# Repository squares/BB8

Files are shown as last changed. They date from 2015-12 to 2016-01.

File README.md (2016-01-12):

// ROAD MAP //

Version 1.0 - Complete

-->  CURRENT 1.5  - I have sound sort of working.  I'm trying to get this working in the least intrusive way possible. Ideally, you'll be able to just buy a wave shield from adafruit and slam it into the top of the arduino and be done with it. That's the hope anyway.

Version 2.0 - Sound Module - Will include randomized sounds that play at randomized intervals.  Perhaps integrate an external power switch.

Version 3.0 - External stimulus for sound module - Considering IR, zigbee, wifi, raspberry pi interface, others.

Version 4.0 - Likely final - Will provide open ends for communication with external components (body, other network devices)... Perhaps moving the audio out of the dome into the body.

//
UPDATE 2016-01-12

Patrick Stefanski was awesome enough to design a modified dome plate and a holder.  This allows you to secure the USB power brick vertically inside of the dome and provides access to the charging port (and slightly useful power-test button) on the bottom of the USB charger.

Once I find time, I'm going to attempt to hack together a power switch onto a USB cable and drop another hole next to this so you can turn the lights on and off without ever having to open up the dome.

UPDATE 2015-12-27

For whatever reason, git desktop decided not to push up the stl's and the png that contains the breadboard layout version of the schematic.  I corrected that and those files are now available.  A couple of things about the breadboard layout:

* - Don't use 220ohm resistors on the entire RGB LED.  Every RGB LED I've seen uses something different.  Mine took 100ohm resistors on the green and blue pins.  Just check the data sheet for whatever you buy.
* - The diagram also doesn't show the power indicator LED.  This is totally optional, but I like being able to verify that the board is getting power.
* - This can be compressed significantly, using the board I show in the parts list. Look at either of the Board images in the images folder for an example.  Board2 is the latest approach, and allows you to create a wiring harness with the common cathode pin glued to the anodes.  This way, you can just plug in the entire block and not have to fiddle with it.  This version also requires less soldering.  I'll put up a picture of the solder points shortly.
* - Last but not least... just wanted to add a quick note that you probably shouldn't run this off the 5v pin. I do.. and my LEDs are BRIGHT.  But I have no idea what that's going to do to the life of my LEDs.  I imagine they will burn out quicker, but I run my board infrequently enough that I won't mind printing and replacing the LED harnesses eventually. Anyway, just wanted to drop a note about that consideration.

//

If you've found this repo, you're interested in adding internal electronics to your BB8 Dome.


All of the options I'd seen involved using every single pin of an arduino to light the logic panels on the dome.  Unfortunately, that removed the ability to do anything more interesting with the lighting, because you'd very quickly run out of PWM capable pins. So, I decided to create a version that utilizes shift registers to extend the capabilities a bit.



I’ve finally finished version 1.0 of my standalone lighting for the dome. I’ve had a lot of people ask me to post schematics, code, and parts lists… and I finally feel like it’s at a good point to do so. 

Regarding the schematic - The schematic shows 220ohm resistors for ALL of the LEDs. This is incorrect. The green and blue legs for the RGB LEDs generally use a lower value resistor. In my case, they’re using 100ohm resistors. Please check your spec sheets for whatever RGB LEDs you get.

Regarding the program - The program requires three libraries (included in the archive). ShiftPWM, which allows you to extend the number of addressable LEDs using shift registers. Arduino Thread, which facilitates (or simulates anyway) multi-threaded operation, and LogicBlock, which is custom code that I’m writing. The sketch itself, along with the LogicBlock library, are the two components of this that I’ve written from the ground up, and will be modifying over time. In future releases, I’ll only be including those two components.

Regarding the parts list (<a href="https://docs.google.com/spreadsheets/d/1KzJZGZxBMD4uZg5txSiHm7NLZ_BNpFicUeiCb588h9Q/edit#gid=0">Google Sheets Parts List for BB8 Internals</a>)- So, full disclosure: I’m VERY impatient. I buy everything on Amazon Prime, because I’m going to get whatever it is in two days, in most cases. So the links I’ve included in the parts sheet are all to amazon prime pages. You CAN find these parts cheaper elsewhere.. you can also likely find them in smaller quantities… for what it’s worth, I found that you’re really only saving a couple bucks elsewhere… but you might have better sources than me. I’ve been really happy with the quality of the parts I’ve ordered.

As a result of my Amazon purchase history, I have a surplus of parts… and as such, I’m willing to put together parts kits for those of you that are willing/able to solder your own setup. I’ve broken down the cost per part for everything I used in my build, and listed that out in the parts sheet. Just to be totally clear, I’m not marking up the price of each part, but I am charging a couple of bucks “handling” for getting everything bagged in anti-static container and organized into envelopes/packages.

I’ve also designed an enclosure to house all of this and keep it looking nice inside my dome. I’ll be happy to share the STLs for that if anyone is interested… but it’s pretty purpose specific to the board I’ve designed.

All of that said, there have been several people that have asked me if I would build this for them, and I’m willing to do that. I’ve included a few options for how that can happen (purchasing arduinos, optional parts, etc) in the parts list spreadsheet. If you think that’s something you might be interested in, feel free to reach out and we can discuss what you might need.

TO DO
-----
* Write up assembly instructions
* Update schematic to reflect 100 ohm resistors, and include power indicator led
* Continue working on v2 (sound add-on)

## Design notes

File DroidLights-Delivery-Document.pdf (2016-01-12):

Thank

you

for

buying

a

set

of

DroidLights.
Before

you

do

ANYTHING…
Please

take

a

moment

to

read

the

guidelines

and

disclaimers

at

the

end

of

this
document!

Now

that

all

of

that

is

out

of

the

way… let’s

get

started!

Upon

opening

the

package,

you

you

find

that

I

have

assembled

the

DroidLight

kits

completely.

If

you

want

to

jump

ahead

and

start

your

lights

up,

skip

ahead

to

the

“CONNECTING

TO

THE
ARDUINO” section.

You

should

be

able

to

immediately

plug

in

the

power

adaptor,

and

have
lights

flickering

away.

The

lights

will all

pulse

for

around

5

seconds

(or

approx.. 3

pulses),

and
then

start

cycling

through

random

behaviors.

In

the

very

unlikely

event

that

any

of

the

lights

come

unplugged

from

the

board during
shipping,

or,

if

in

the

future,

you

wish

to

swap

out

the

LEDs

for

some

reason,

please

skip

below
to

the

section

labeled

“WIRING

HARNESS

INSTALLATION”.

I’m

making

every

effort

to

ensure
that

the

lighting

system

arrives

completely

in

tact,

but

things

can

shift

in

transit.

All

I

can
guarantee

is

that

the

lighting

system

was

100%

functional

per

my

specs

when

I

closed

up

the
package.

INSTALLING

YOUR

DROIDLIGHTS

I’ve

printed

the LED

housings

per

the

specs

outlined

in

the

group’s

documentation… however,
it’s

entirely

possible

that

the

printer used

for

your

dome

parts

is

calibrated

slightly

differently,
and

the

lenses

are

likely

not

to fit

right

out

of

the

box.

There

are

several

approaches

to

making
a

nice

fit,

but

the

one

I’ve

found

works

best

is

as

follows:

1. First,

ensure

that

the

dome

openings

are

smooth

and

free

of

excess

paint/filler/support
materials.

We’re

looking

for

as

smooth

and

square

as

possible

finish

inside

there.

Test
the part

to

see

if

it

fits

into

the

opening

(first

time

through,

it

likely

won’t)
2. Lightly

sand all

four

outside

edges

of

the logic

housing.

I

printed

these

with

several
shells,

so

you

should

be

able

to

sand

quite

a

bit

without

causing

any

major

issues,

but
just

start

with

a

light

sand

on

each

edge.
3. Repeat

step

1.

That’s

it

really… just

slowly

wear

away

the

logic

housing

until

the

light
fits

into

the

opening. You’re

going

for

a snug

fit.

It

shouldn’t

require

a

great

deal

of
force

to

push

in,

but

likewise,

shouldn’t

just

pop

out.

You

can

also

carefully

round

the
front

face

to

make

the

initial

insertion

easier.

But

keep

in

mind,

that

the

lower

logic
housings

are

very

close

to

a

seam,

and

there’s

not

a

lot

of

material

printed

around
there… if

you

force

them

in,

you

run

the

risk

of

cracking

your

dome.

So

shape

them
appropriately.

4. If you

do

over-‐sand,

and

the

lenses

no

longer

stay

in,

a

drop

of

hot

glue should

be
sufficient

to

hold

it

in place.

The single

red

radar

LED is

only

slightly

more

complicated

to

install.

For

my

dome,

I

hot

glued
the

LED

into

the

back

of

the

radar

eye

internals,

and

then

fed

the

wires

into

the

dome

through
the

surround.

If

you’ve

glued

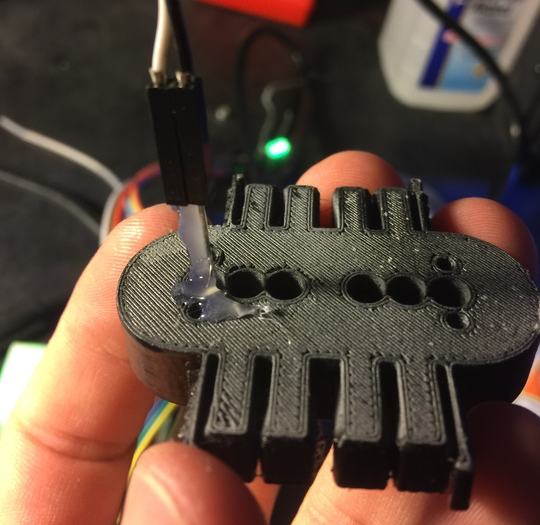
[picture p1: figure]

together

your

radar

eye,

or

have

another

issue

that

prevents

you

from

doing

it
this

way,

then

you may

need

to

drill

out

an

access

hole

to

feed

the

radar

eye

in

from

the

back.

Included

in

the

Dome

STL

files

is

a

housing

for

the

PSI

LED.

It’s

a

small

disc

with

an

indentation.
I

recommend

printing

this

piece,

and

then

using

hot

glue

to

adhere

it

to

the

back

of

the

PSI.
Once

you’ve

done

that,

you

can

simply

insert

the

LED

into

the

opening

there.

Finally,

the

Holoprojector.

You

should be

able

to

use

the

included

mounting

ring

and

just

press
fit

that

into

the

back

of

the

holoprojector. Again,

this

is

printed

to

match

the

recommended
settings

for

the

files

in

the

group

FAQ,

but

the

piece

may

need

minor

adjustment

to

fit,

or

a

dab
of

hot

glue

to

stick.

(PS

– I

recommend

hot

glue

in

most

of

these

cases

because

it

holds,

but

it’s

not

necessarily
permanent. LEDs last quite

a

long

time,

but

not

forever.

I’ve

used

resistors

that are

slightly
larger

than

necessary

in

the

hopes

that

the

LED

will

last

even

longer,

but

it’s

entirely

possible
they

will

burn

out

and

need

to

be

replaced.

Please

think

twice

before

supergluing,

or

otherwise
permanently

welding

the

housings

to

LEDs

to

your

dome.)

WIRING

HARNESS

INFORMATION

The

complete

lighting

system

consists

of

6

wiring

harnesses.

3 with

the

LED

logic

housings

(aka,

the

clear

plastic

blocks)

and

3

that

are

just

LEDs.

They

all

look

similar,

but

have

important

differences.

In

the

list

below,

I

will

describe

how

each
differs

and

how

they

plug in

to

the

DroidLight module. Don’t worry

TOO

much

about

plugging
things

in

wrong.

If

you

miss

a

socket

with

a

pin,

or don’t

get

the

ground

pin

in,

the

worst

that
will

happen

is

one

of

the

lights

may

not

turn

on… or

may

turn

on

at

the

wrong

time… just
unplug,

and

re-‐plug.

On

to

the

lights!

Please

refer

to

the

image

below

as

you

read

through

the

wiring

connections.

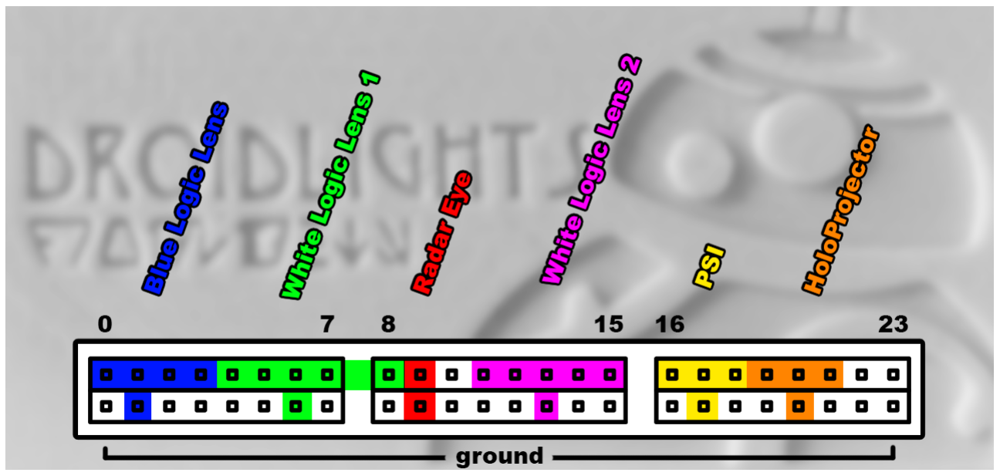
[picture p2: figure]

1. Blue

Logic

Lens – This

cluster

of

lights

will

go

in

the

Logic

hole

farthest

to

the

left,

if
you’re

looking

directly

at

the

radar

eye. Notice

the

plug-‐end

of

the

harness.

You

will

see
four

rows

of

pins

along

the

top,

and

one

lonely

pin

at

the

bottom.

The

top

pins

are

what
drive

power

to

the

LEDs

and

the

bottom

pin

is

a

ground.

This

harness

is

marked

in

blue
in

the

diagram,

and

goes

from

position

0

to

position

3.

(This

is

all

zero-‐based,

to

match
with

the

code.)

2. White

Logic

Lens

– There

are

two

of

these

that

are

identical

in

size,

but

one

of

them

has
a

different

set

of pins

(insert

photo

of

pins). At

the

moment,

it’s

not

important

which
group

of

lights is

the

top,

and

which

is

the

bottom when

placed

into

your

dome,

but

it’s
important

that

this

cluster

plugs in

second,

as

marked

in

green

in

the

diagram.

This
harness

starts

at

socket

4,

and

goes

to

socket

8.

3. Next

comes

the

radar

eye

LED.

This

is

the

one

set

of

wires

that

has

no

black

wrapping.
The

white

line

is

the

power,

and

the

black(or

gray…whichever

one

isn’t

white) line

is

the
ground.

It

plugs

in

next

in

series,

and

is

marked

in

red

in

the

diagram

at

position

9.

4. Next

is

the

second

white

LED

cluster.

This

resides

either

above

or

below

the

one
identified

in

step

2.

You’ll

notice

that

this

one

has

5

pins

right

next

to

each other,

with
no

break.

This

plugs

into

the

board

starting

at

position

11,

and

goes

all

the

way

to
socket

15

(marked

in

pink

on

the

diagram)

5. Next, we

have

the

two

larger single

LEDs. In

the

package,

I

have

placed

a

white
attachment

on

the

end

of

one

of

them. The

one

WITHOUT

the

white

attachment

will

be
the

one

we

use

to

light

the

PSI.

Insert

that

into

the

board

starting

at

position

16
(marked

in

yellow

on

the

diagram).

6. Finally,

the

HoloProjector.

This

is

the

light

with

the

white

ring

attachment.

This
attachment

is

optional,

if

you’ve found

another

way

to

mount

the

LED

to

the
holoprojector,

but

I

hadn’t so

I

created

this.

Attach

this

to

the

board

immediately next
to

the

PSI

plug,

starting

at

position

19

(marked

in

orange

in

the

diagram).

CONNECTING

TO

THE

ARDUINO

All

of

the

lights

should

now

be

attached

to

the

board.

The

next

step

is

to

verify

that

the

wires
coming

out

of

the

light

module

are

connected

to

the

Arduino.

I

will

have

disconnected

these
for

shipping,

so

verify

that

the

wires

are

connected

as

follows:

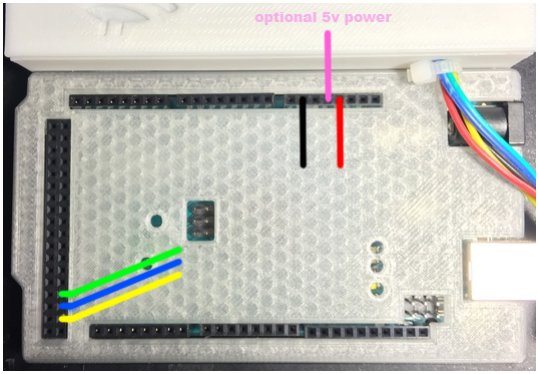
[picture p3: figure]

Note:

There

is

an

option

for

the

red

power

wire.

The

red

dot

on

the

enclosure

(and

in

the
diagram)

is

for

3.3v.

This

is

the

lower

of

the

two

power

options

for

the

board.

Once

you

get
power

running

through

the

board,

you

may

notice

that

the

LEDs

aren’t

as

bright

as

you’d

like.
The

socket immediately to

the

right

of

the

3.3v

socket

(marked

on

the

drawing

above

in

pink,
but

not

marked

on

the

enclosure)

is

the

5v

socket. You

CAN

use

this,

and

your

LEDs

will

be
brighter,

but

this

applies

more

wear

on

the

module

and

LEDs,

and

of

course

eats

up

power
faster.

I’ve

been

running

my

lights

on

the

5v

pin

for

around

a

month

now

with

no

negative

side
effects

but

just

be

aware.
In

general,

I

make

tiny

color

coded

marks

on

the

enclosure

for

the

Arduino to

show

you

where
each

pin

should

go.

Once

you’ve

got

them

all

plugged

in,

it

will

look like

this:

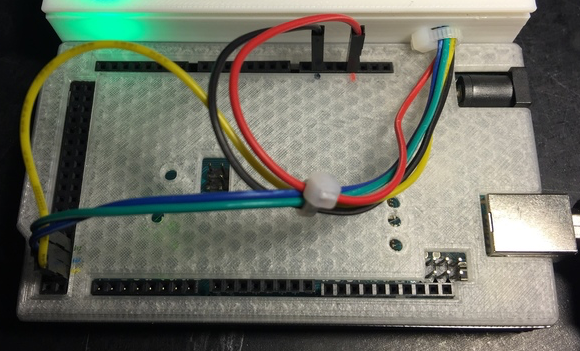
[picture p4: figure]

Once

all

of

the

lights

have

been

attached,

you’re

clear

to turn

everything

on!

In

the

package,
you’ll

see

a

white

block

USB

power

brick,

and

a

black

cable.

Plug

the

black

cable

into

the
Arduino via

the

port

in

the

housing,

using

the

black

cable.

Power

will

instantly

be

provided

to
both

boards.

You

should

see

a colored

indicator

light

on

the

DroidLight housing,

and

all

of

the
LEDs

should

stay

lit

for

a

period

of

5

seconds.

After

5

seconds,

the

lights

should

start

pulsing
slowly,

and

randomly

changing

modes!

At

this

point,

if

you

don’t

see

an

indicator

light

on

the DroidLight housing

(green

in

this
example),

then there

is

no

power

getting

to

the DroidLight board.

Double

check

the

wire
connections

between the

DroidLight module

and

the

Arduino.

If

you

see

the

board

indicator

light,

but

none

of

your

LEDs

are

lighting… first,

reset

the

Arduino
by

unplugging

power,

waiting

a

few

seconds,

and

plugging

it

back

in.

If

you’re

getting

SOME

lights

on,

and

other’s

are

not

on… unplug

and

reseat

them

into

the
housing.

It’s

important

that

both

the

power

and

ground

pins

are

correctly

seated into

the
sockets.

(Note:

the

position

of

the

ground

pin

doesn’t

matter,

as

long

as

it’s

completely

in

any
socket

hole

in

the

bottom

row).

At

this

point,

all

of

your

lights

should

be

lit,

and

going

nuts!

Now

it’s

time

to

prep

your

dome
and

lights

for

the

best

fit.

USB

POWER

SUPPLY:
I

selected

a

USB

power

supply

that

I

felt

had

the

best

combination

of

weight

to

capacity. This
power

supply

should

be

able

to

power

the

DroidLights

module

for

several

hours

without
interruption.

Feel

free

to

replace

this

with

any

other

portable

USB

charging

device.

To

recharge, use

the

included

USB

-‐>

Micro-‐USB

cord,

and

plug

into

any

USB

power

source.

Note:

The

current

batch

of

USB

power

supplies

included

have

something

that

looks

like

a
power

button

on

them. Unfortunately,

this

isn’t

an

actual

power

button,

but

it

will show

you
how

much

power

is

available

in

the

device,

which

is

handy

in

its

own

way.

Power

to

the

lights

is
currently

controlled

by

plugging

and

unplugging

the

cable.

SOFTWARE

UPDATES:
I

will

include

instructions

for

software

updates

as

they’re

made… but

in

general,

these
instructions,

along with

all

of

the

files

and

reference

photos,

will

be

stored

in

the

following
GitHub

repository:

https://github.com/squares/BB8

I

will

post

notices

of

the

software

updates

to

the

Facebook page

(and

the

website,

once

it’s

set
up)

and

you

will

be

required

to

download

and

install

any

updates

applicable

to

you.

Again,
instructions

will

be

provided

at

that

time,

if

you’re

interested.

QUESTIONS

YOU

MIGHT

ASK:

Why

are

the

plugs

in

the

order

they’re

in? Why

is

are

there

two

spaces

between

the

radar

eye
plug

and

the

next

logic

light

plug?

This

is

a

combination

of

the

way

the

code

works,

the

prototyping

process,

and

the

position
within

the

dome.

The

pins

are

where

they

need

to

be

for

everything

to

work

correctly.

The

space

next

to

the

radar

eye

is

there

purely

because

the

radar

eye

pin

is

little.

I

wanted

to
give

my

fat

fingers

a

little

extra

room

to

reach

in

there

and

put

the

plug

in.

Also,

it

lines

the
second

set

of

white

LEDs

up

nicely

with

the

edge of

that

header.
J

Any

other

questions?

Please

reach

out

via

email

to

strong.s@gmail.com.

Send

me

pictures

of
your

build!

Thanks!
Steve

GUIDELINES

AND

DISCLAIMERS:

1. Make

sure

your

dome

is

ready! It’s

tempting

to

shove

this

into

an

unfinished

dome,

and
while

I’ve

done

my

best

to

make

the

DroidLight module

robust

enough

for

mild

abuse,
it’s

a

hand-‐built

piece

of

electrical

equipment, and

pulling

it

in

and

out

of

a

dome
multiple

times

may

lead

to

something

breaking.

This

product

is

intended

for

use

in
“finished” domes.

Use

in

any

other

way

is

totally

your

responsibility

I’m

not

responsible
if

you

break

it.
2. No

two

printers

print

exactly

the

same

dimensions,

regardless

of

how

well

they’re
calibrated.

Don’t

attempt

to

force

any

parts

into

any

openings.

Follow

the

instructions
below

and

aim

for

a

good

fit! The

LED

housings

MUST

be

sanded

prior

to

inserting

into
the

openings.

You

WILL

break

your

dome

if

you

shove

them

in

before

sanding. I’m

not
responsible

for your

dome

breaking.
3. Things

can

shift

in

transit.

I

will

make

every

effort

to

pack

this

in

a

way

that

everything
arrives

in

tact

and

ready

to

go,

but

it’s

possible

a

pin

might

bend

in

the

wiring

harness.
Double

check

that

each

plug

has

straight

pins

before

you

plug

them

in

to

the

board.
4. I

can’t

be

held

responsible

for

any

damage

to

your

dome

(belongings,

house,

dogs,
children,

etc).

I’ve

used

this

system in

my

own

dome

for

over

a

month

now

without
issues,

but

the

universe

works

in

mysterious

ways

and

things

happen.

Again,

this

is

a
hand-‐made

piece

of

electrical

equipment,

and

if

it’s

handled

as

such,

I’m

sure

you’ll
enjoy

it

for

a

long

time.

If

you

mount

it

to

the

top

of

your

car

and

drive

through

a

rain
storm… Well… basically,

once

it

leaves

my

possession,

I’m

not

responsible

for

it.
5. Feel

free

to

modify

the

board

in

any

way

you’d

like!

Heads

up

though,

I

will

try

to

make
myself

available

for

information

as

time

permits,

but

I

won’t

be

able

to

fix

broken
boards

remotely.

If

you

need

me

to

fix

something,

you’ll

have

to

cover

shipping

costs
both

ways,

and

there

will

be

an

hourly

rate

for

repairs.
6. NOTICE:

There

is

no

warranty

on

kits.

It

is

your

responsibility

to

install

the

board.
Opened

kits

cannot

be

returned.

Be

careful

if

you

use

a

battery

source

that

is

capable

of
delivering

a

lot

of

current.

Contact

a

professional

if

you

need

assistance.
7. One

last

time,

just

for

good

measure:

Steve

Strong

assumes

no

responsibility

for

the
misuse

of

this

kit.

Thanks

for

reading

all

of

that!

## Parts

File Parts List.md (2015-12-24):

For now, I'm storing the parts list in a google spreadsheet:

<a href="https://docs.google.com/spreadsheets/d/1KzJZGZxBMD4uZg5txSiHm7NLZ_BNpFicUeiCb588h9Q/edit?usp=sharing">BB8 Parts List 1.0</a>

When I create a new major version, I will add another link.

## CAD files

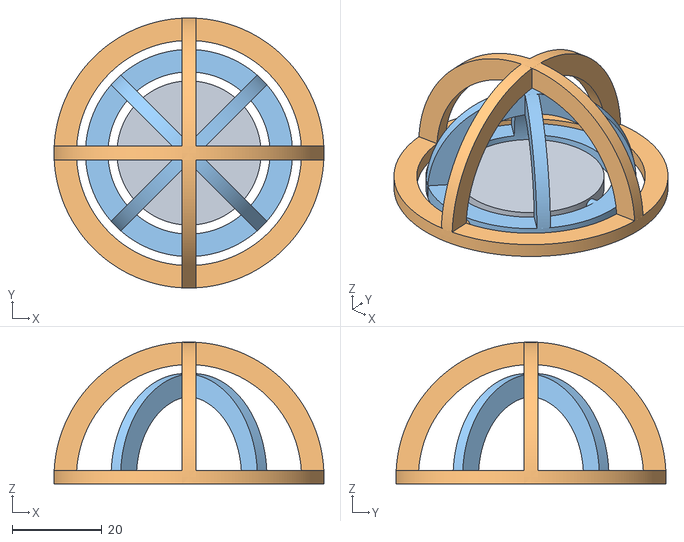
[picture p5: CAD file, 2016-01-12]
Ball/gimbaltest.stl
60.0 x 60.0 x 31.5

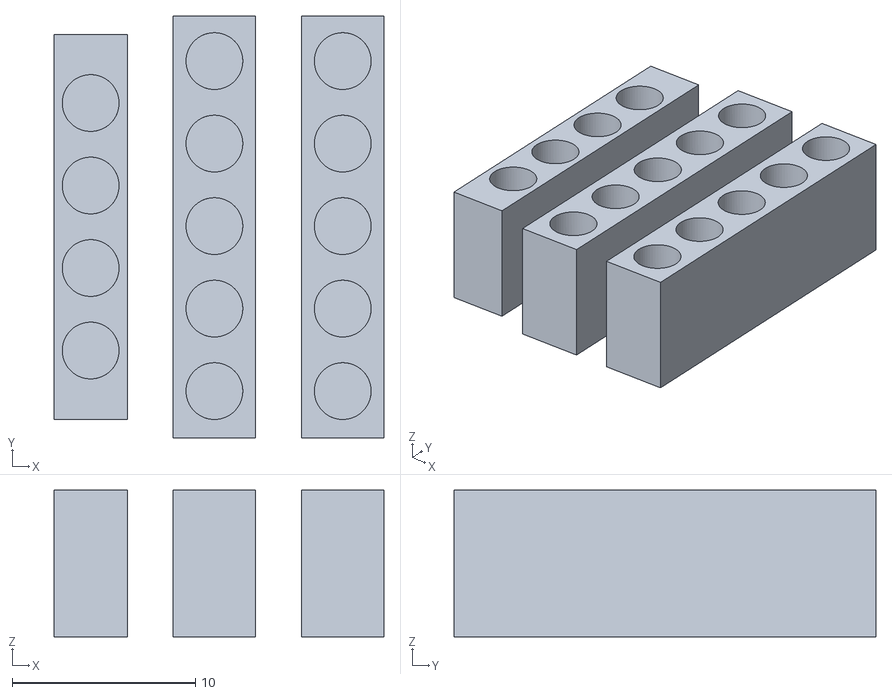
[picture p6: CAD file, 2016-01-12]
LogicLenses-NoPSI.stl
18.0 x 23.0 x 8.00

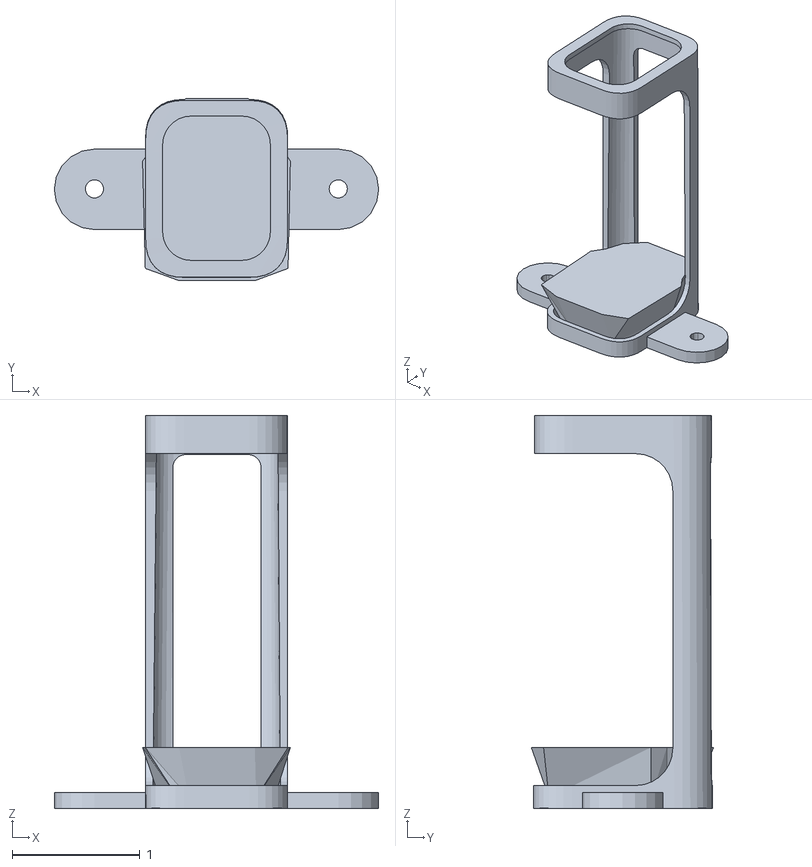
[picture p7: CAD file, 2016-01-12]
ModifiedDomePlateAndUSBPowerHolder/PowerHolder_withSupportBlock.STL
2.54 x 1.43 x 3.07

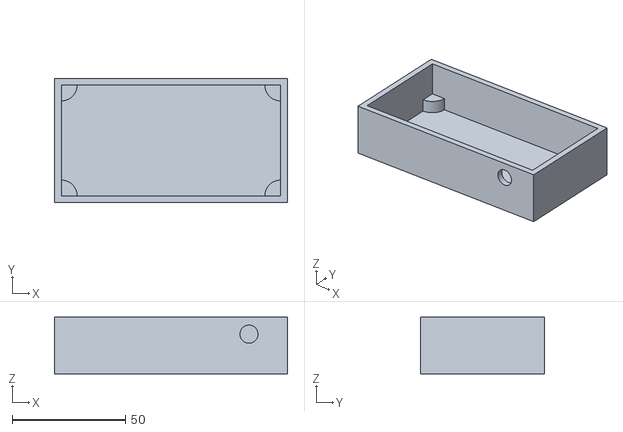
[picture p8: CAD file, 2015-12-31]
Enclosure-Box5.stl
103.0 x 55.0 x 25.0

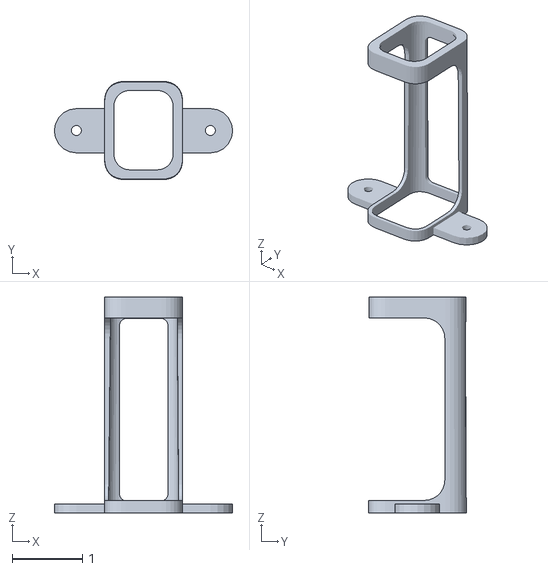
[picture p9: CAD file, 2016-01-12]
ModifiedDomePlateAndUSBPowerHolder/PowerHolder.STL
2.54 x 1.40 x 3.07

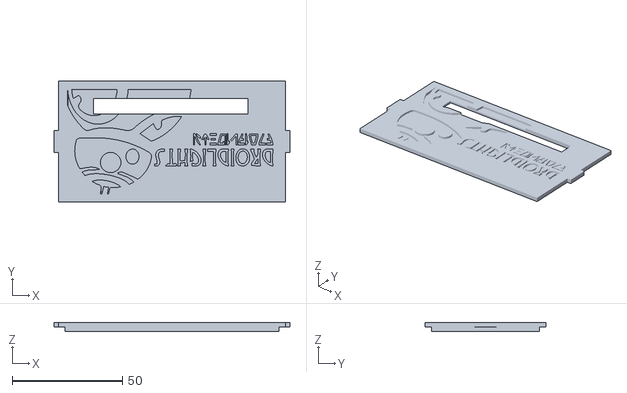
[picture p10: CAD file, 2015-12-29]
Enclosure-lid-external2.stl
107.0 x 55.0 x 3.90

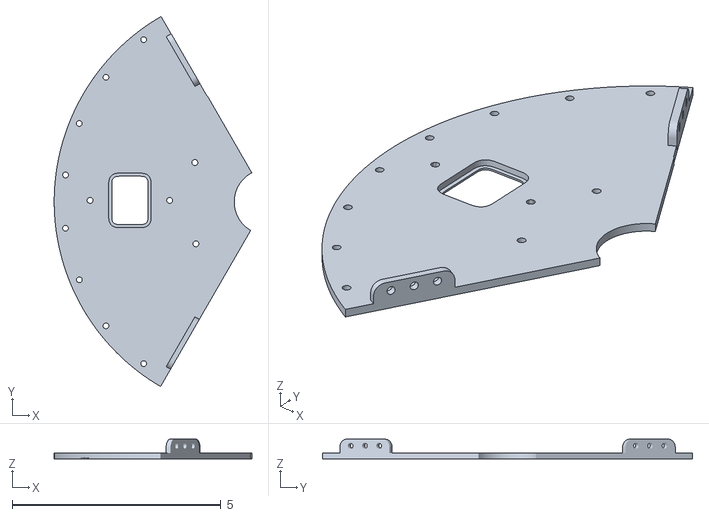
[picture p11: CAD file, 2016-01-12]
ModifiedDomePlateAndUSBPowerHolder/ModifiedDomePlate.STL
4.73 x 8.86 x 0.472

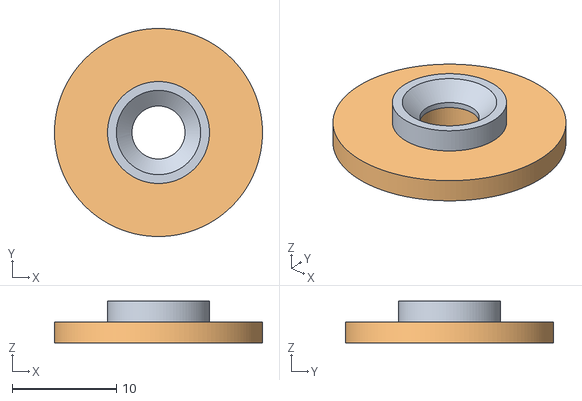
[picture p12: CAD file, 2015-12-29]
HoloProjectorInsert.stl
20.0 x 20.0 x 4.00

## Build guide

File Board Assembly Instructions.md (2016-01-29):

_THIS IS A (MOSTLY COMPLETE) WORK IN PROGRESS FOR ASSEMBLY INSTRUCTIONS_

_I CAN'T BE HELD RESPONSIBLE IF YOU BURN YOUR HOUSE DOWN. USE COMMON SENSE_

# BOARD ASSEMBLY INSTRUCTIONS

## Parts Needed:
* [Google Sheet Parts List](https://docs.google.com/spreadsheets/d/1KzJZGZxBMD4uZg5txSiHm7NLZ_BNpFicUeiCb588h9Q/edit?usp=sharing)

## Tools Needed:
* Soldering iron with a fine tip
* Solder
* Helping Hands tool
* Multi-meter
* Hot glue gun
* Probably some kind of magnification or really good eyeballs.
* Light
* Time
* Patience

## GENERAL NOTES BEFORE WE START: 
* These instructions assume you have at least a moderate knowledge of soldering.  You're working with relatively small soldering points.
* It's further assumed that you should be testing your connections as you go to verify that current is passing correctly.
* I will refer to the "Top", "Bottom", "Left" and "Right" of the board in these instructions.  These terms will almost always refer to looking at the chip-side of the  board straight on, unless otherwise noted.
* In these instructions, I describe WHAT to do, and in general, WHY to do it that way, for practical purposes.  I don't describe HOW to solder... or WHY this all works.  I'm happy to discuss those issues in separate conversations, but I think it would make these instructions the size of a novel to get into that depth.
* For the purposes of clarity, I talk about the socket pins in terms of pin numbers in relation to their final position in the board.  With the socket placed horizontally with the top surface facing you, pin 1 is in the top left... counting across to pin 8.  Pin 9 is in the bottom left, and pin 16 is in the bottom right.  This is how I've always thought of them when soldering, so that's how I'll write it out here.  Hopefully that's not too confusing.

(insert drawing with numbered pins).

* Read through ALL of the instructions first, to make sure you understand everything before starting.  If you have any questions, feel free to reach out and ask and I will try to clarify. I've had to desolder major sections of boards before because I didn't realize something, and that sucks.

## With that out of the way, lets DO THIS!

**Step 1:**

Solder the three sockets to the board.  Why do we use sockets? Well, the truth is that these guys MIGHT be getting a little more power than they're spec'd for.  I've been running mine for many, many hours without issue... but it's POSSIBLE that they may get burnt out over time. Hell, everything gets burnt out over time... but we want the shift registers to be as easy to replace as possible, since they are doing most of the work.

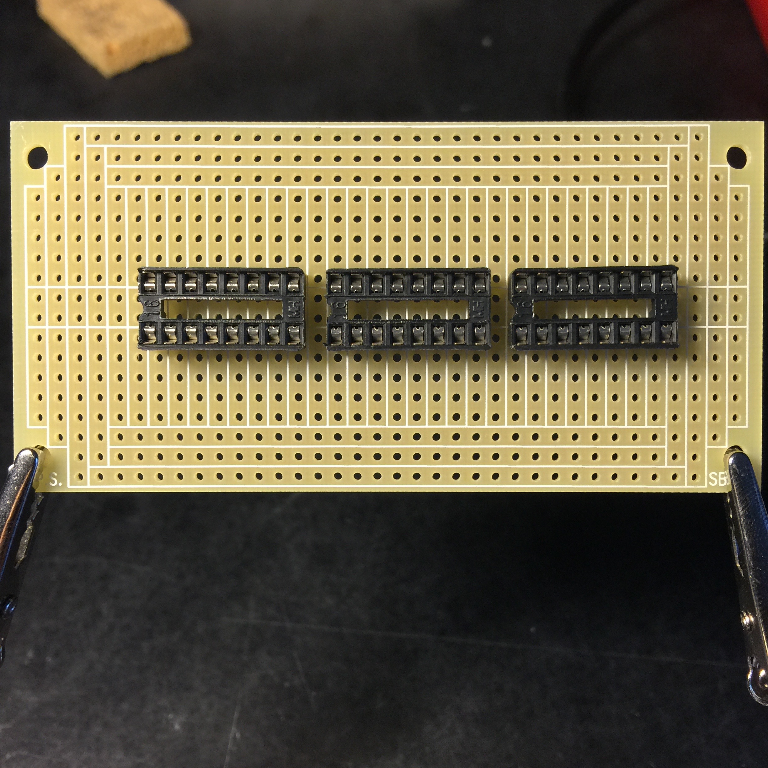
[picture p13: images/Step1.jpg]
Step 1 - Sockets in board


The first socket should be in the 7th hole.  I have another version where the first socket is in the 5th hole, but I found the 7th hole to involve less soldering down the road.

The sockets should be soldered with one space between them. 

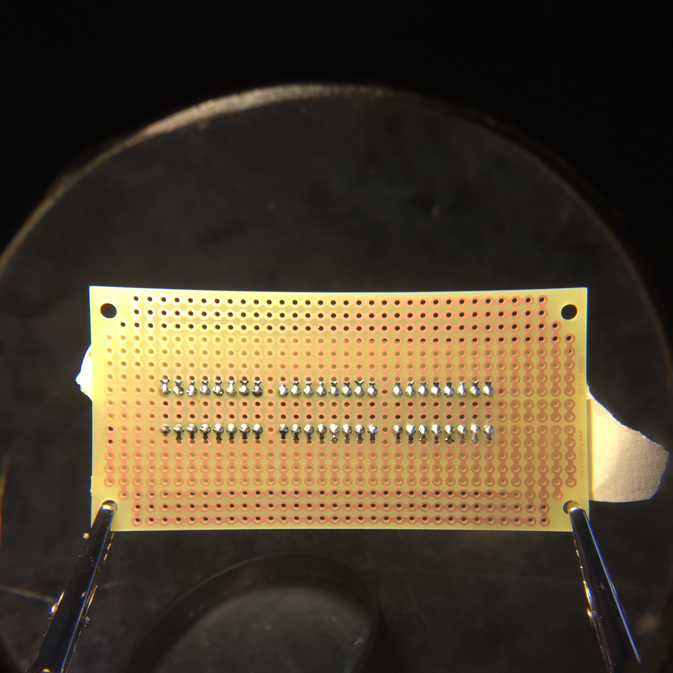
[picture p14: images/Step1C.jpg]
Step 1C - Sockets in board - Soldered


**Step 2:**

This is one of the most annoying things to solder...  The 74hc595 shift register uses the second pin on the top side of the IC to control the 0th output. Thus, the reason we left a space between the sockets.  We're going to take a short length of wire, and bend it around the left side of the socket, so that it ends one pin to the left of the socket's 9th pin.

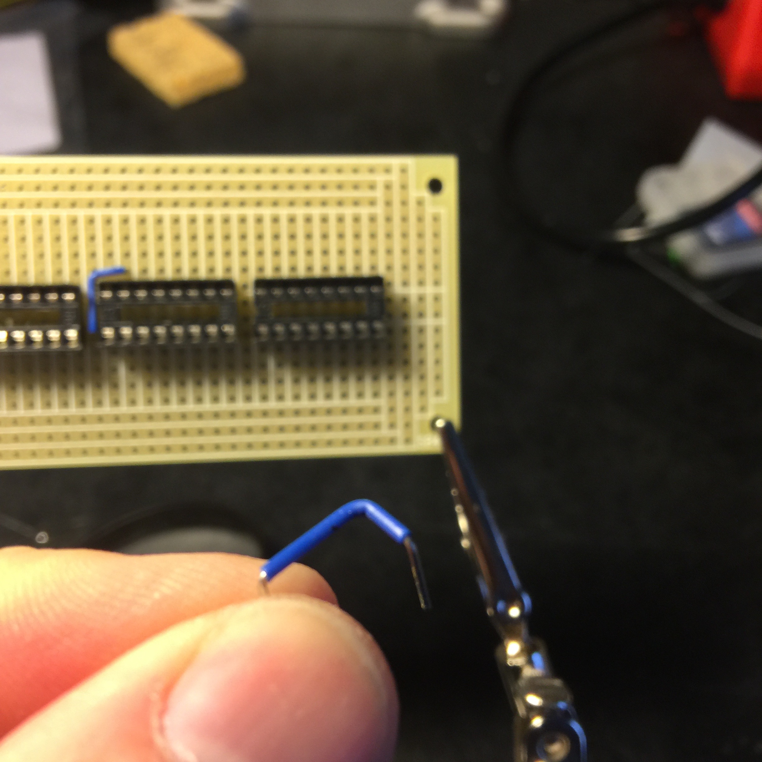
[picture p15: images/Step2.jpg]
Step 2 - 0th LED wire

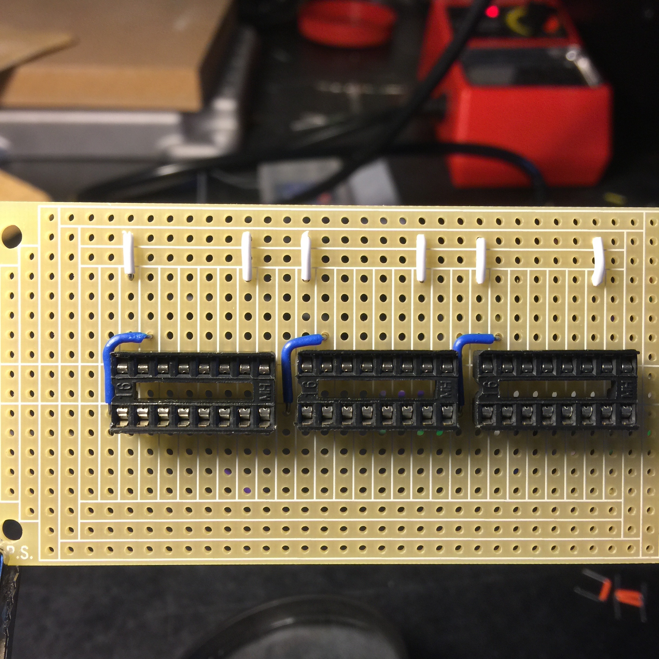
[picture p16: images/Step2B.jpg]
Step 2 - 0th LED wire


Now that this it out of the way, everything else is relatively easy.

**Step 3:**

For this board, we're using the second top rail as the power rail.  You'll want to solder two short wires connecting pin 1 and pin 7 of each of the sockets  to the power rail. To save as much space later for wiring, connect them from the absolute top position of the terminal strip.

Step 3 - Power Connection

NOTE:  It's really easy to get mixed up with positions in this sort of work. Always double check that you're running a wire to the correct start and end position before soldering. Unsoldering is a pain in the ass.

**Step 4:**

Each socket is grounded from the 4th pin.  For this layout, we're using the absolute top rail of the board as the common ground.  So run a wire from the top terminal strip position on the 4th pin, to the ground rail for each socket.

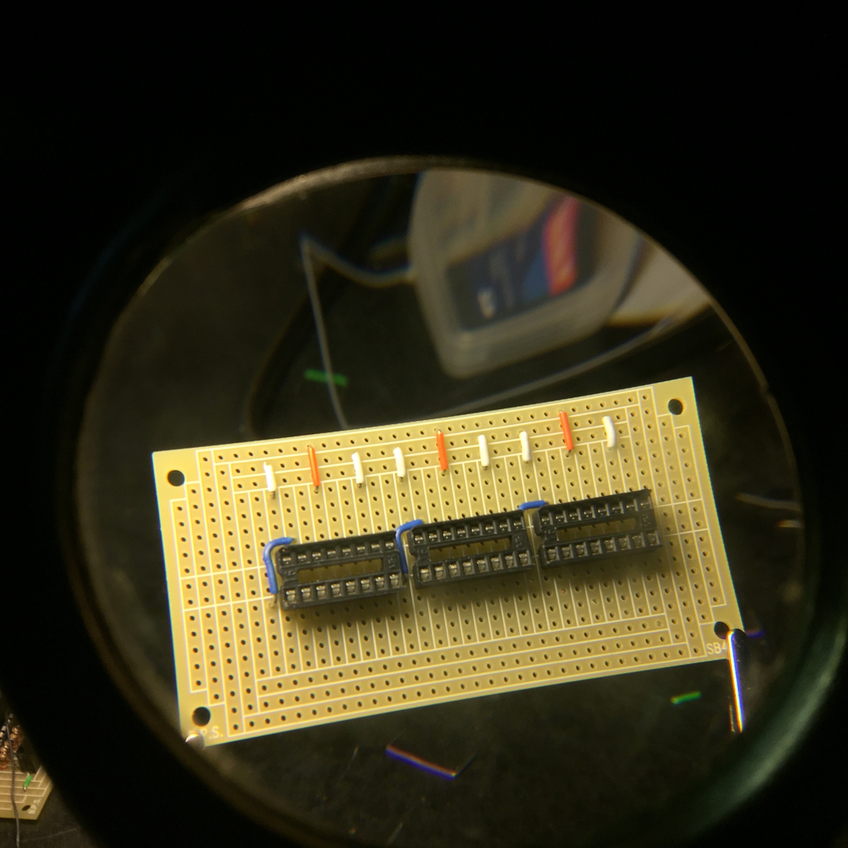
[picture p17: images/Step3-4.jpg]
Step 4 - Ground Connection


**Step 5:**

Shift registers are awesome, and you can daisy chain them together infinitely, provided you have enough power to drive them safely... which I guess means it's not infinite, but WHATEVER.  So we're going to chain these sockets together.  The three terms you want to remember are "data", "clock", and "latch". I won't go into what each of those are right now... but suffice to say, these are the three lines that will control the way the LEDs turn on and off.

For my boards, I like to keep all of the data, clock and latch connections the same color.  This helps me troubleshoot later should something stop working. The data INPUT pin on the chip is the 3rd pin across the top side of the board, and it is being output on the 8th pin on that same side.

So, starting with the rightmost socket, connect the 3rd pin on socket 3, to the 8th pin of socket 2.  This will overlap the 0th LED pin. Just make sure that there are no exposed wires touching.  Alternatively, you can get fancy and have it curve around the top.  Whatever you think looks better :)

Repeat this from the 2nd to the 1st socket.

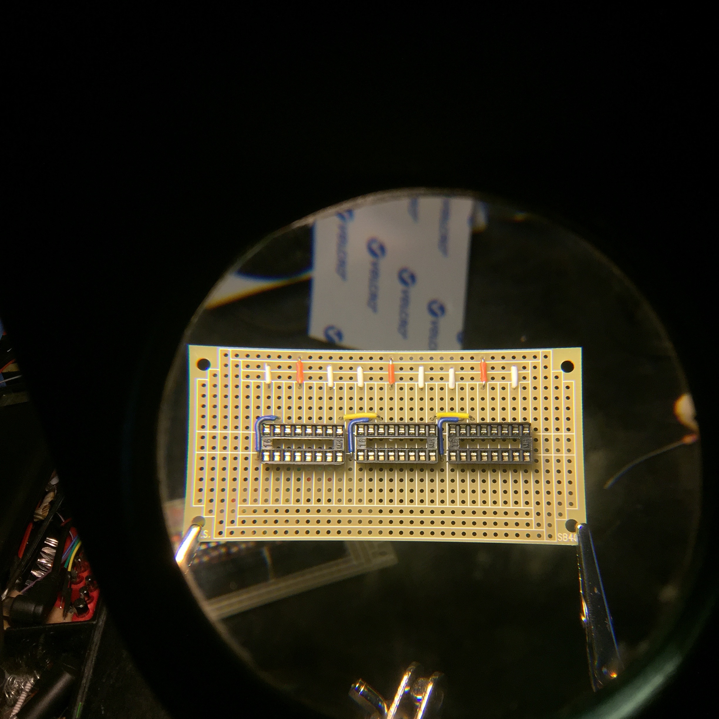
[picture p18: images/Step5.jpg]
Step 5 - Data Connections


**Step 6:**

Now for the "clock" line.  All of the ICs use the same pin to manage the clock.  This is the 6th pin.  So we're going to solder a wire from the 6th pin of the socket 3 to the 6th on the socket 2, and then repeat that from socket 2 to socket 1.

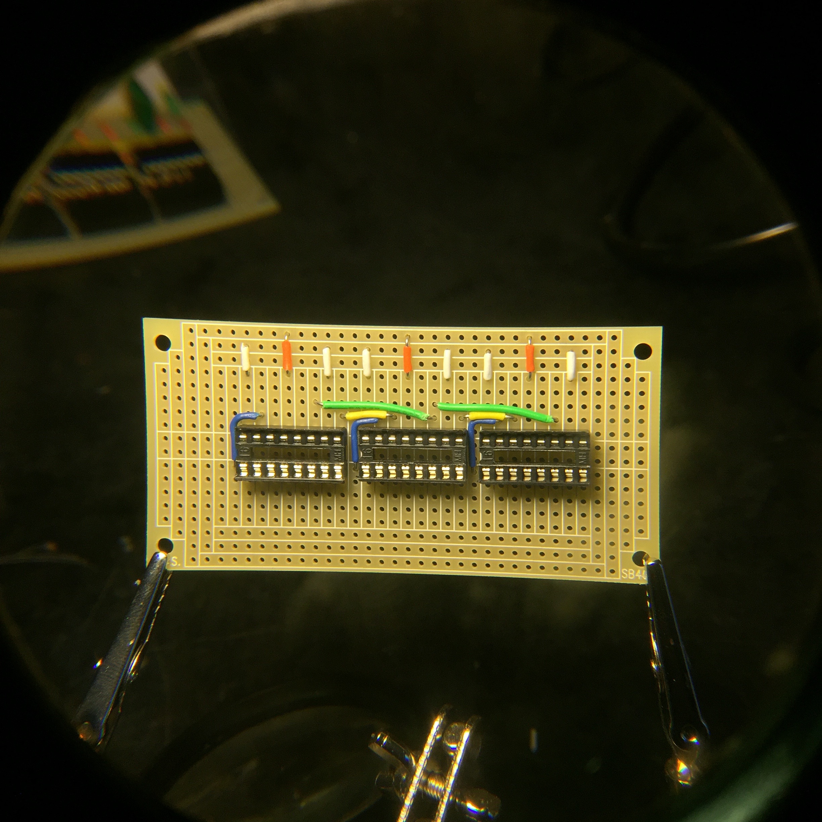
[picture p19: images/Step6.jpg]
Step 6 - Clock Connections


Notice, that for these connections, I'm shifting one hole up as I go from socket 3 to socket 2.  This lets me drop down one hole in that same terminal strip for that same pin, and keeps things looking nice and tidy.

**Step 7:**
The "latch" line is last, and like the clock line, it occupies the same pin on each of the sockets.  This time, we're connecting the 5th pin of the socket 3 to the 5th of the socket 2. Then repeat this to socket 1.

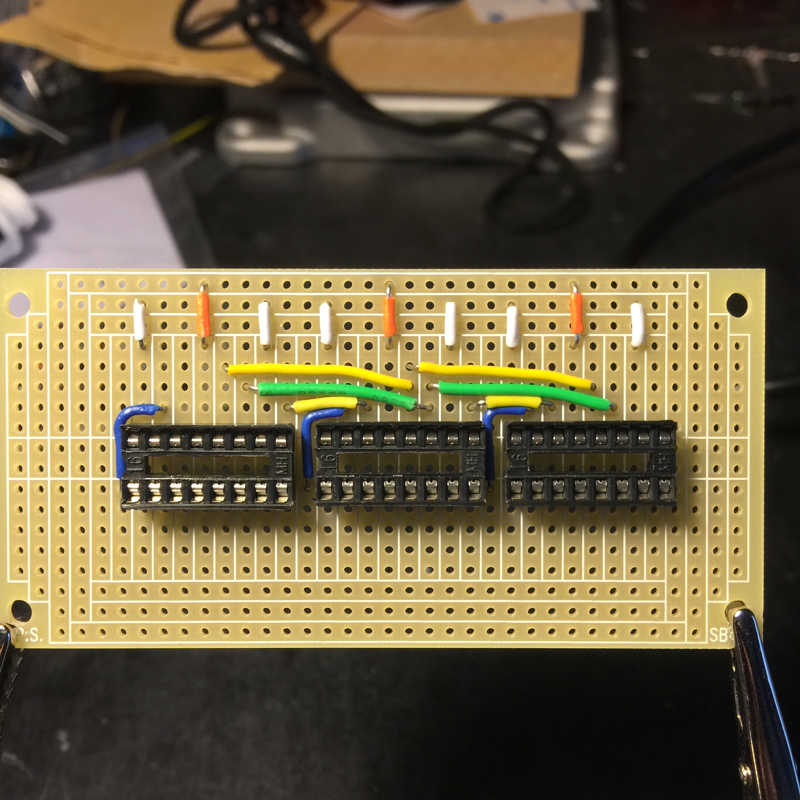
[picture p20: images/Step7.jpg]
Step 7 - Latch Connections


**Step 8:**
Solder one .1uf capacitor to the board for each of the sockets, connecting the 5th terminal strip to ground.  This shares the same terminal strip as the latch line, for reference.

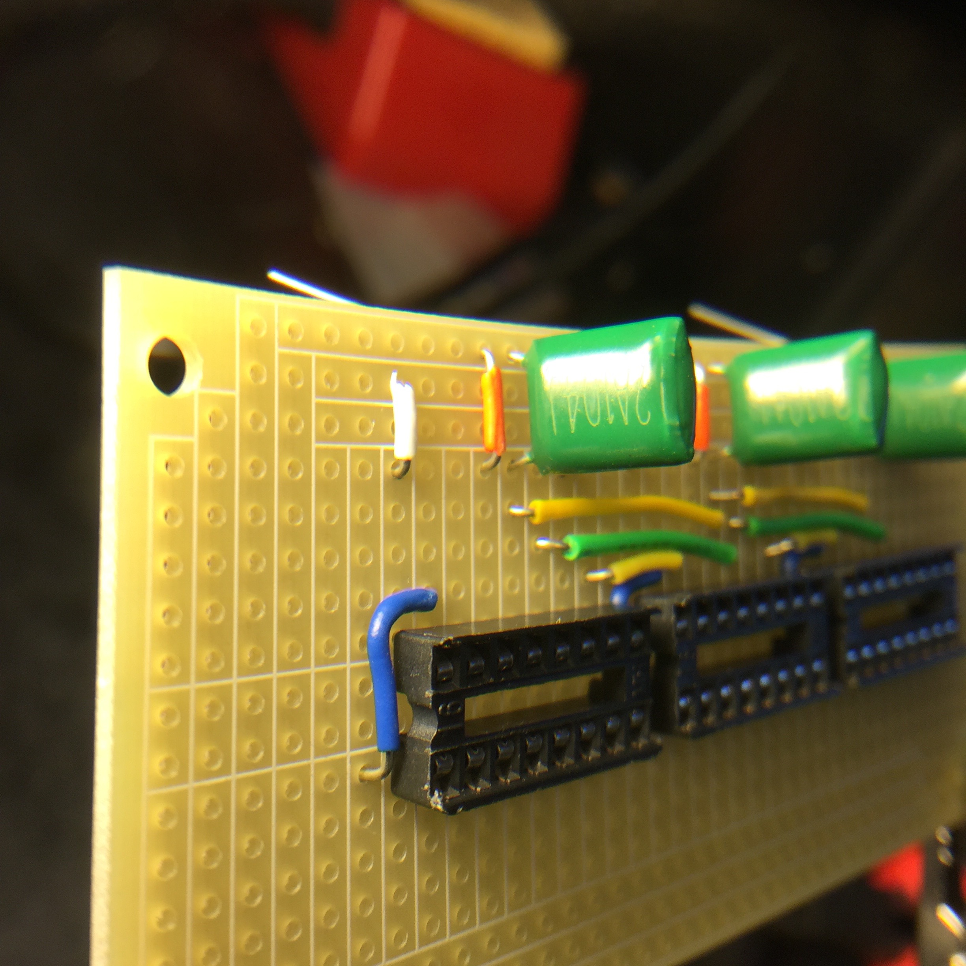
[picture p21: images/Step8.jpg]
Step 8 - Capacitor Connections


**Step 9 (OPTIONAL STEP):**

I personally like to have a power indicator light on my board... if you have one of the parts kits, this explains the extra resistor and green LED ("BB-8 doesn't have any green LEDs... wtf?").  Solder the resistor at the top right of the board at the absolute end of the power rail.  Then solder the LED from where the resistor terminates, back to the ground rail.  Tadaaa... power indicator.

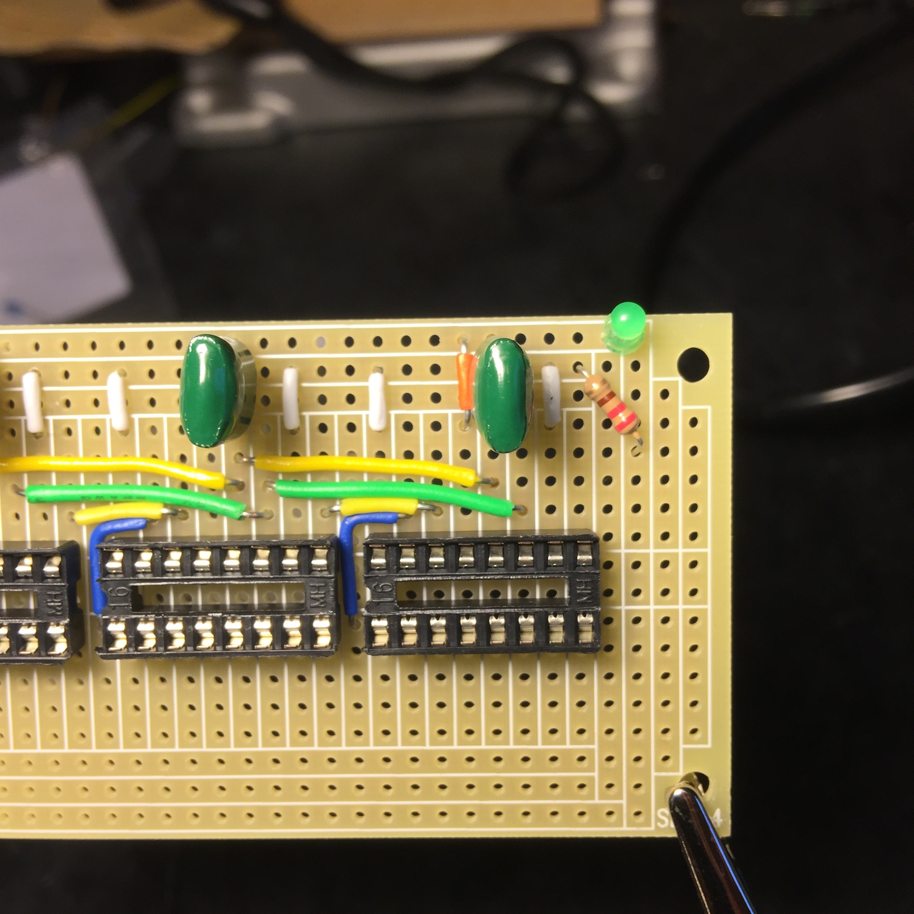
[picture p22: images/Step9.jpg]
Step 9 - Power Indicator Connections


The top half of the board is now complete.  Take some time to stretch or a nap or something :)

**Step 10:**

We need to get a common ground to the bottom of the board.  The prototyping board I reference in my parts list, has three rails across the bottom. For this layout, we're going to use the topmost of those three bottom rails.

To connect this to ground, you will need to use three very short wires, as shown in this photo:

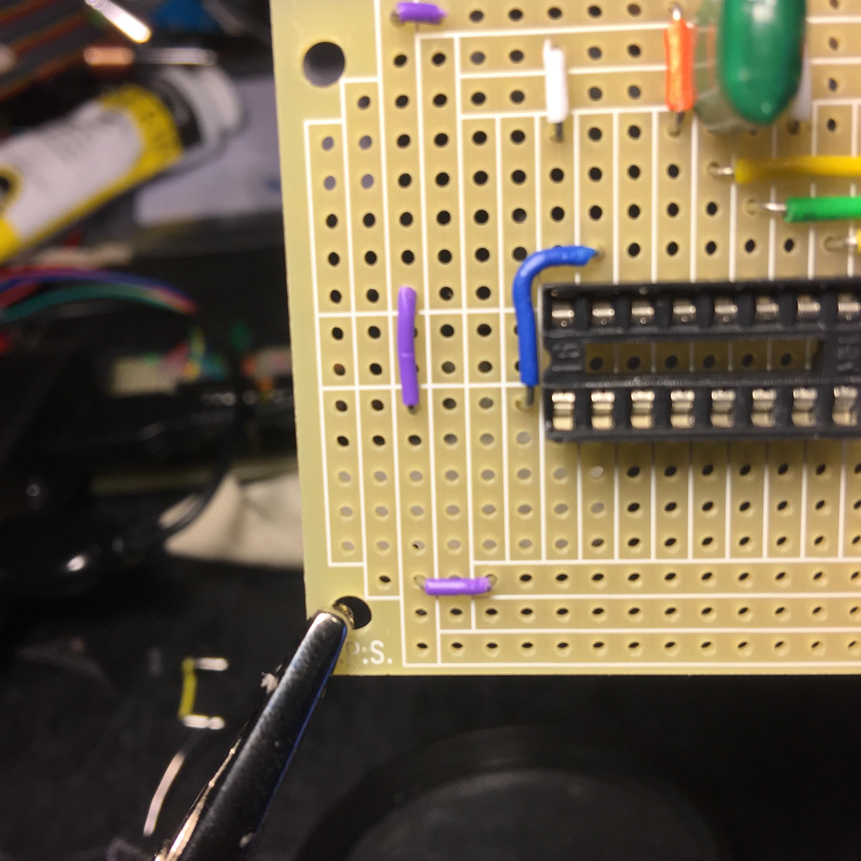
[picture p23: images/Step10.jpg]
Step 10 - Common Ground Connections


**Step 11:**

Each of the sockets will be connected to ground from the 16th pin. Run a very short connection from the bottom of that terminal strip to the ground rail immediately below. On the solder-side of the board, use a sharpie to draw a line between the socket pin and the ground pin that you just soldered.  This will be referenced later.

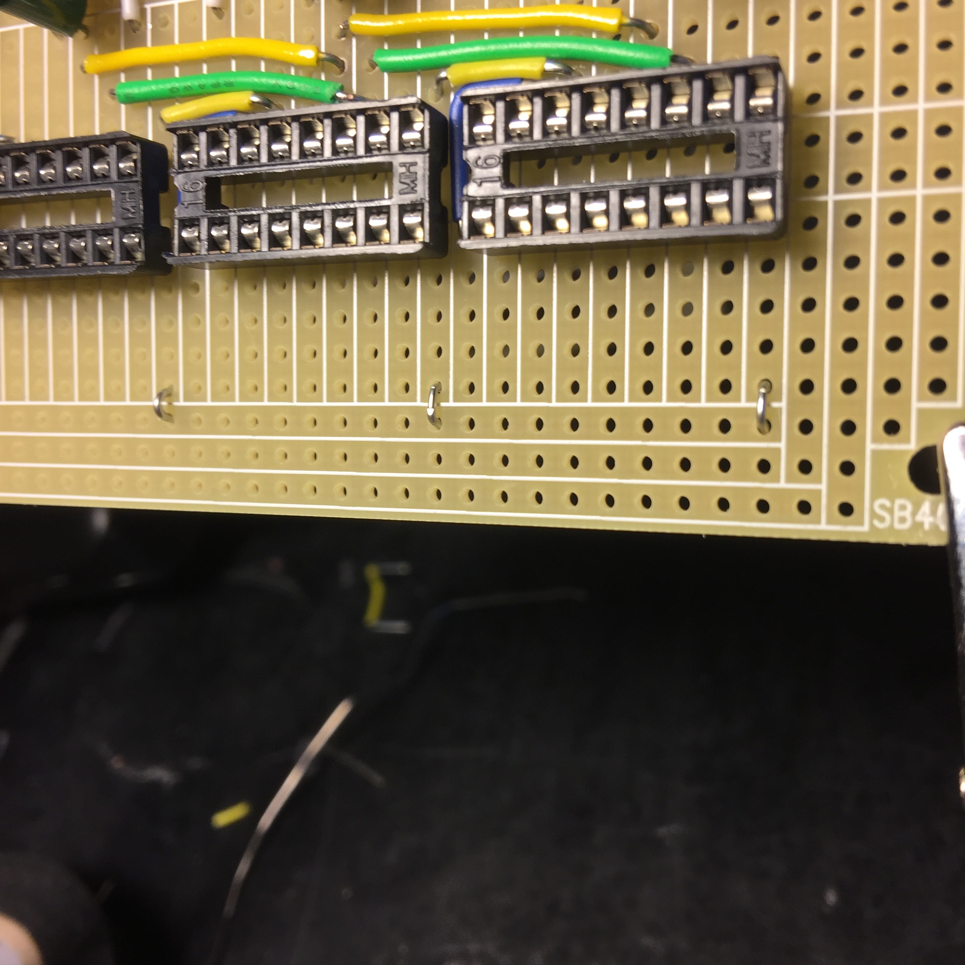
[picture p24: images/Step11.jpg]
Step 11 - Ground Connections


**Step 12:**
Resistor time!  We want to use the bottommost hole of the terminal strip for a header socket... so we need to bend the resistors in a way that allows them to only span 3 holes.  I like to leave one leg straight, and bend down the other leg until it can fit in there correctly.  Also, as a matter of personal preference, I like to bend and place all of the resistors at the same time, and then tape them in place so they all line up nicely. Then, I go through and solder them all in a row.  

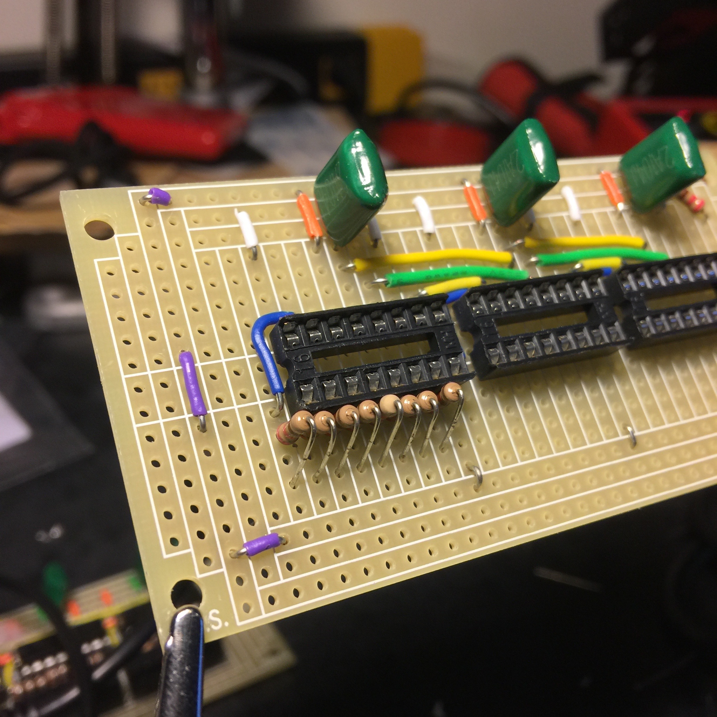
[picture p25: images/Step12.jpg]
Step 12 - Resistor Connections


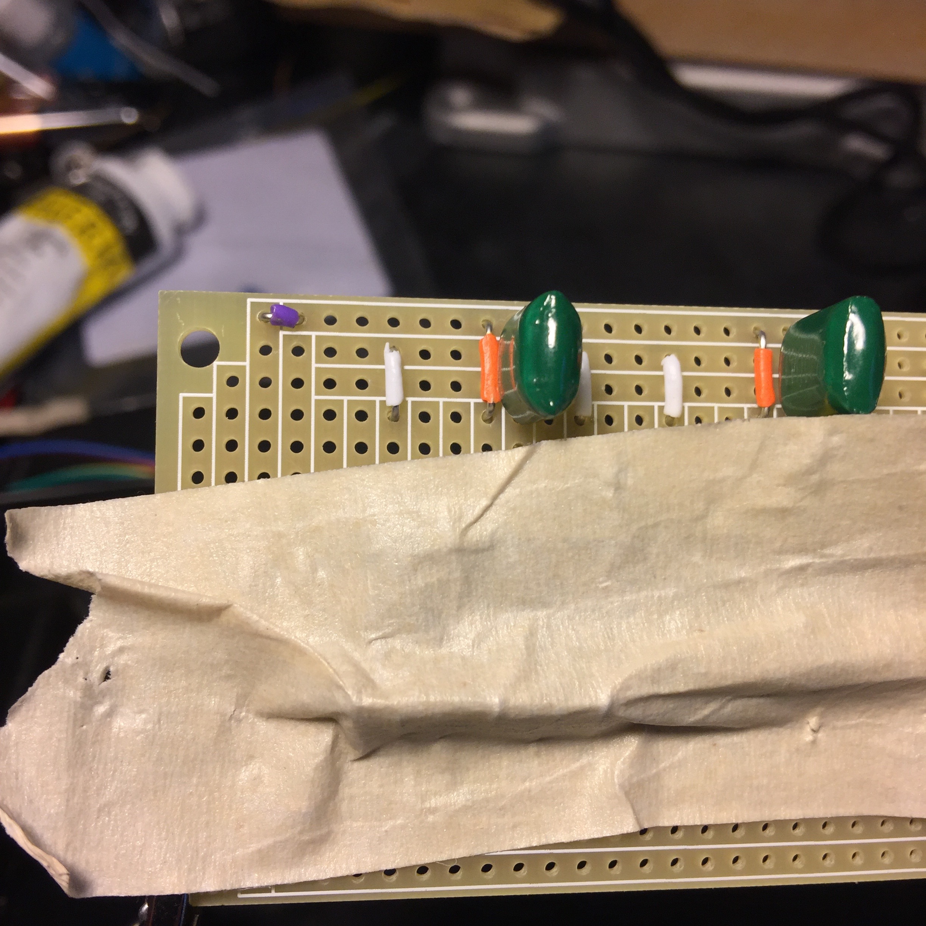
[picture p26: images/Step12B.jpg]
Step 12B - Resistor Connections


Solder one set of 8-pin resistors per the photo... then flip the board over for the next step.

**Step 13:**

VERY IMPORTANT STEP.  I guess they're all very important... but this is one, where if not taken... can ruin your build when you plug it in. 

We all know that current takes the path of least resistance... and we want our current running through resistors... not the terminal strips. If we left the board like it is, then your LEDs would light up briefly at full blast, and probably burn out within a second. So we need to modify our board a little bit.  I usually wait until this point, so I can reference the solder points we made in step 12.  We need to sever the terminal strip between the resistor pins.  To do so, I use a little pointy file, and scrape them, until a test with a multi-meter proves that the connection has been severed there.  I like this board because it doesn't take too much to make this happen, and it's hard to screw up.  Just take it slow and be careful, and don't cut the connection to the ground from step 11 (the sharpie-line!).

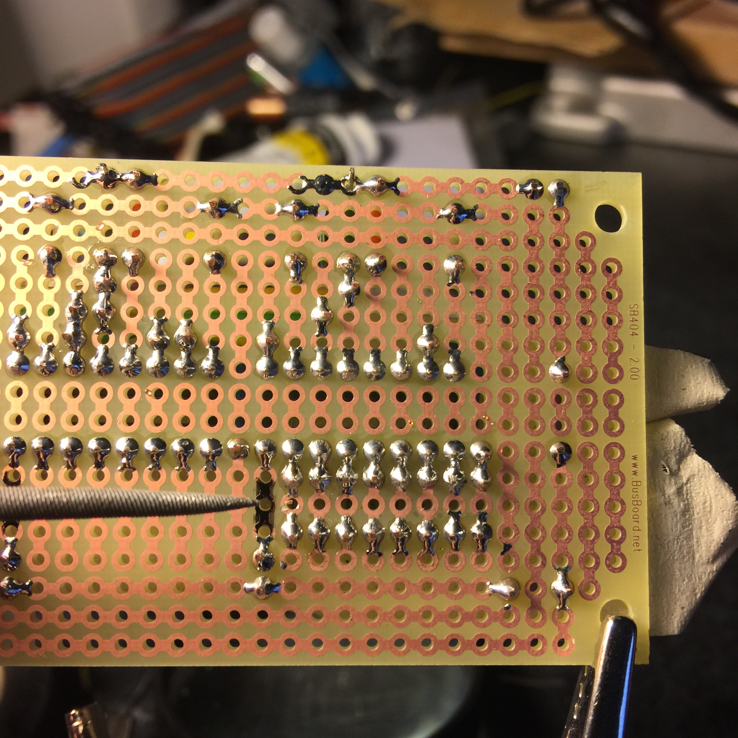
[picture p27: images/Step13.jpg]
Step 13 - BOARD MODIFICAIONS


Once you've identified where the right terminal strip cuts should go, you can repeat this across the next sets of 8... JUST BE SURE TO AVOID THE BLACK LINE YOU DREW WITH THE SHARPIE. We need that connection to the ground.

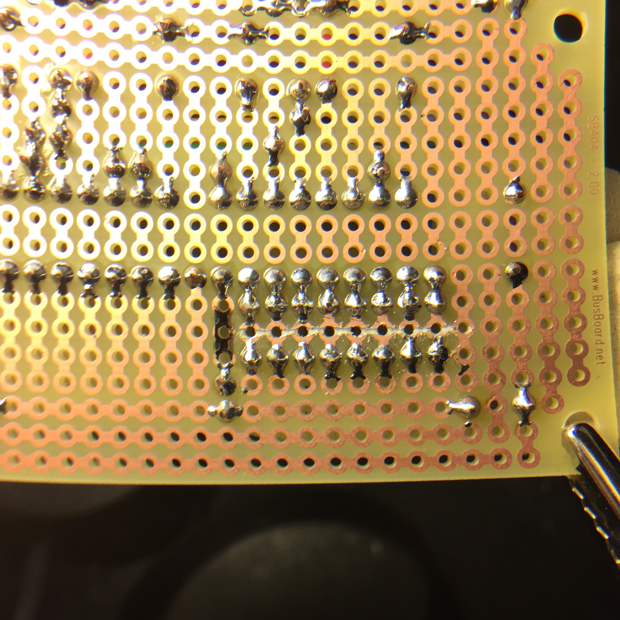
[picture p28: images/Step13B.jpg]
Step 13B - BOARD MODIFICAIONS

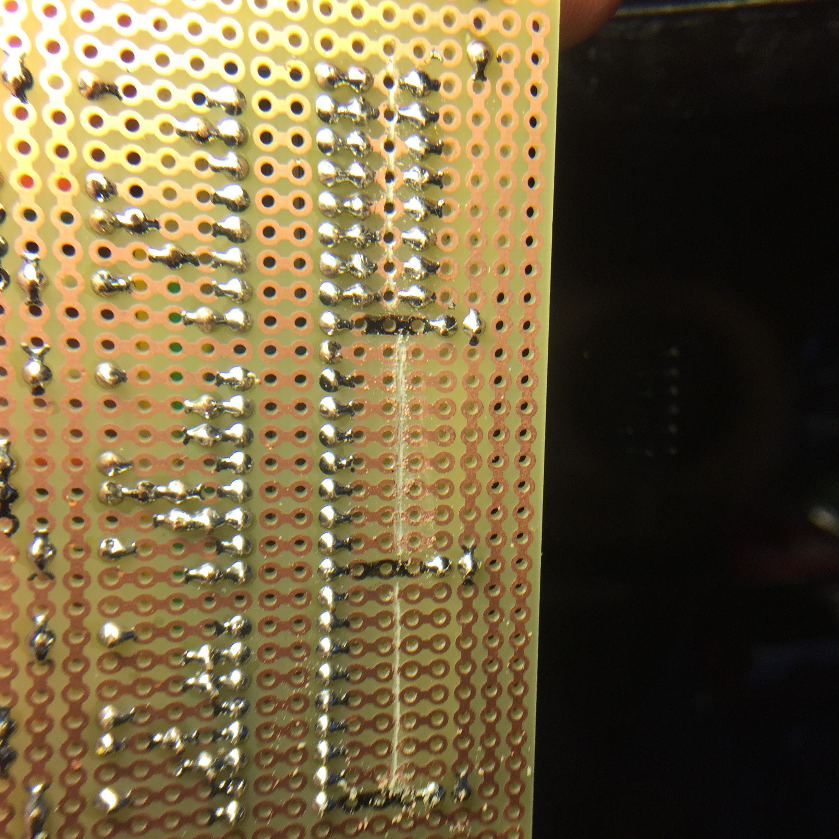
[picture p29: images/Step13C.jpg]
Step 13C - BOARD MODIFICAIONS


Turn the board back over, and repeat the resistor soldering in step 12 for the next two sets of headers.  NOTE:  The RGB LEDs used in my parts list require a different resistor for the green and blue pins.  As such, you can see in the photos that I've left spaces for those, and installed them facing the opposite direction, just so I can clearly see where they sit.

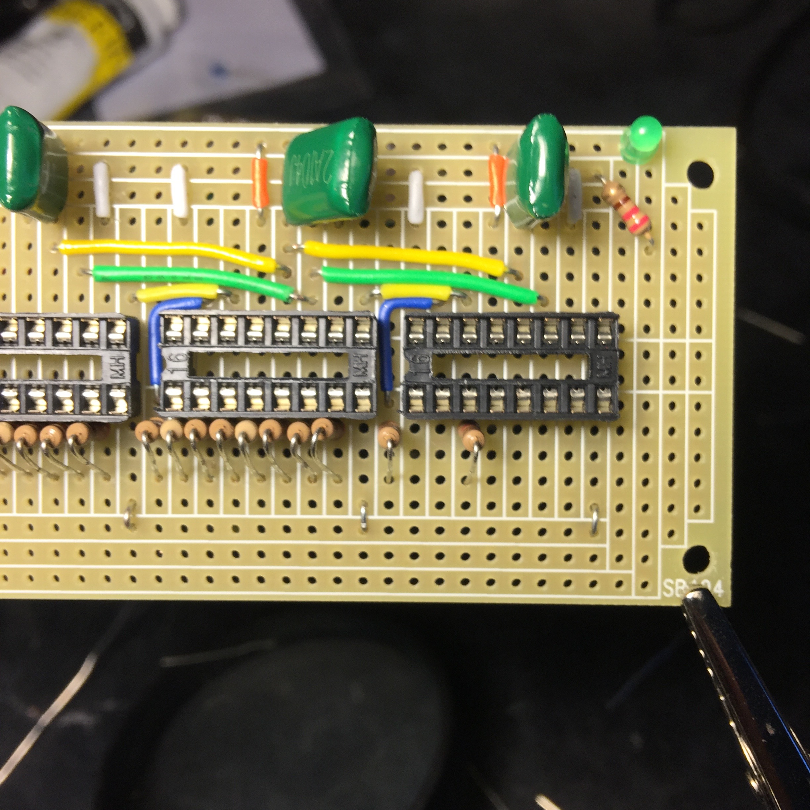
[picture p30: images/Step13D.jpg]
Step 13D - BOARD MODIFICAIONS

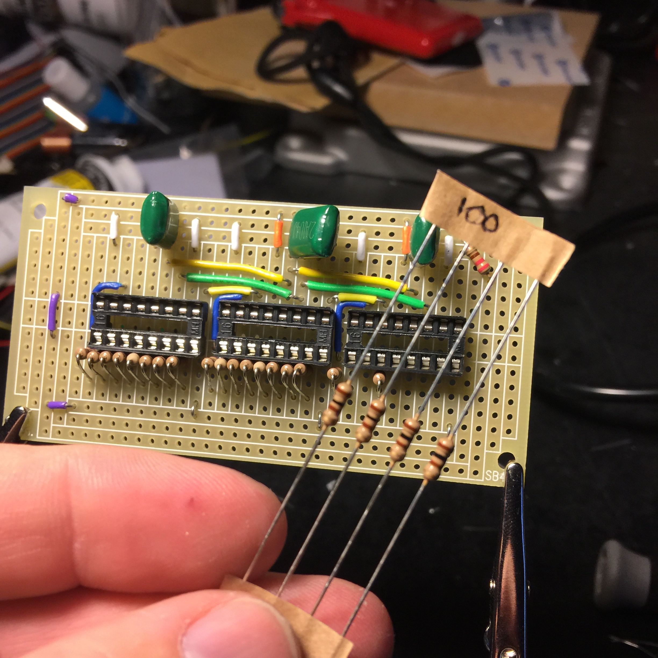
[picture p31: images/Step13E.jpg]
Step 13E - BOARD MODIFICAIONS

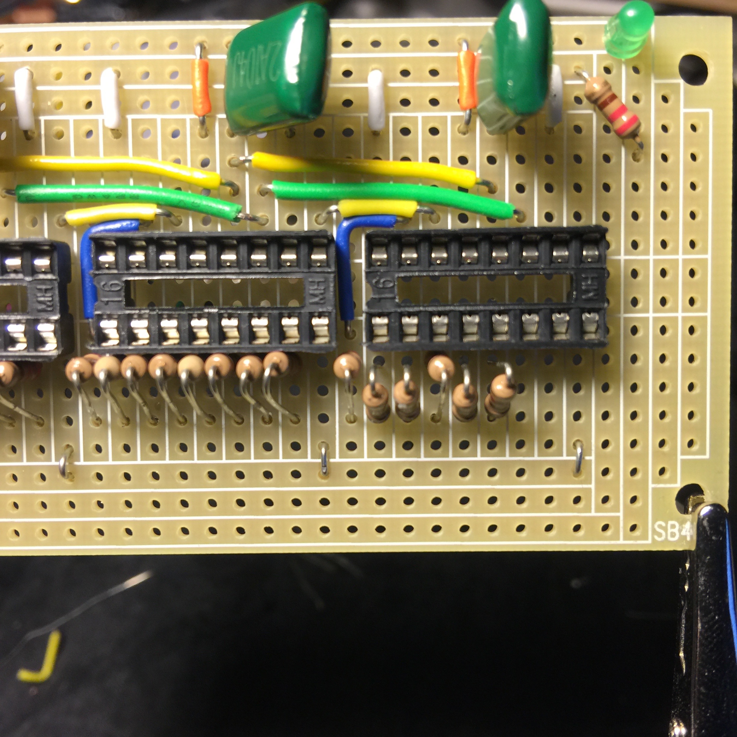
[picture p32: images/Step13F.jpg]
Step 13F - BOARD MODIFICAIONS


**Step 14:**

We're going to use 6, 8-pin headers.  If you bought the bag of headers from my parts list, then you've got a bunch of 40 pin headers to cut into 8-pin sections.  We're shooting for two rows of 8-pins for each section. There are a ton of ways to ensure that your headers go in straight and aligned.  I personally take some male header pins, and connect the tops of the female headers together... then tape that flat to the board... then solder.  I've had good luck with that method.

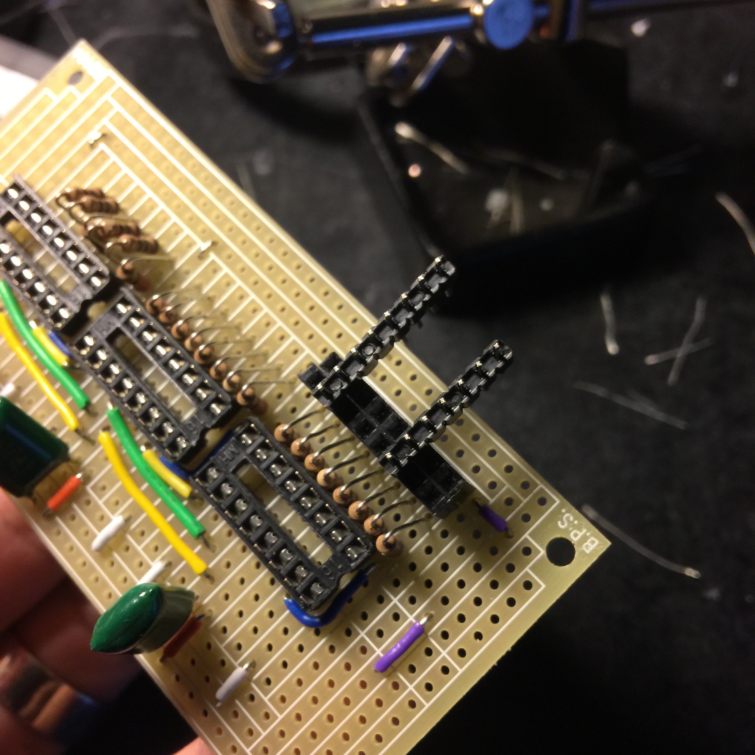
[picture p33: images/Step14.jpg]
Step 14 - BOARD MODIFICAIONS


NOTE: Why 8 pin connections when the dome lights are either 1, 3, 4, or 5 pins?  Well, for me, it's more about the outputs of the ICs. I like knowing that for a given block of 8 header sockets, that one shift register is driving those.  That way, I can more easily troubleshoot a problem.  Also, it allows for me to more easily make changes in the future.  If I want to move all of my wiring harnesses around, and have the 5-pin logic lens first, I can do that.  If you decided that this is going to be the last time you deal with this particular board, and you want to do groups of headers that are the exact size of the lights you're going to plug in, then do them in this order:
4 pins, 5 pins, 2 pin, 5 pins, 3 pins, 3 pins, 2 pins.

**Step 15:**

The board is complete!  Now we just need to create connections for the arduino! For these wires, I've used jumper wires with one male end and one female end.  You will need 5 wires, and I recommend using red and black for the power and ground, and match the colors you used in step 5 for data, latch, and clock for the other three. 

Cut the female end off of each wire, and strip a few millimeters of shielding off to expose the wire, then tin that with solder.

Solder the data wire to an available hole in the terminal strip for pin 3 of Socket 1.

Solder the latch wire to an available hole in the terminal strip for pin 5 of Socket 1.

Solder the clock wire to an available hole in the terminal strip for pin 6 of Socket 1.

Solder the power (red) wire to the leftmost hole in the power rail.

Solder the ground (black) wire to the leftmost hole in the ground rail.

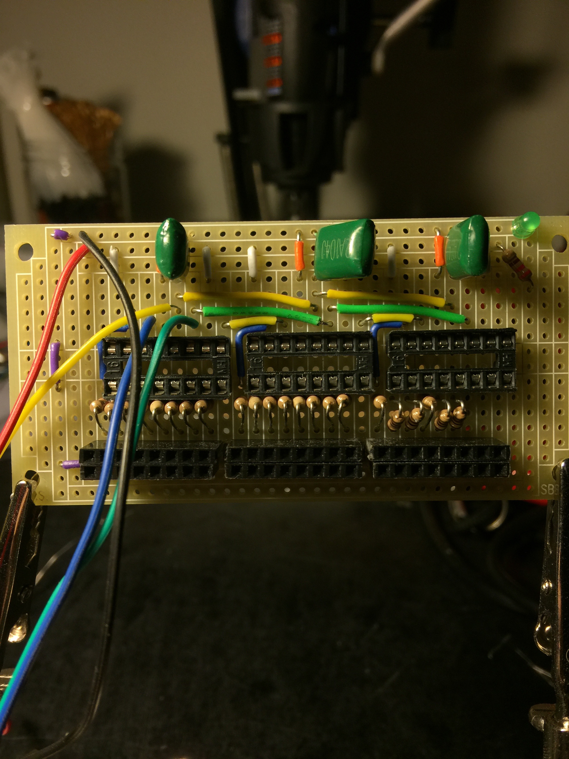
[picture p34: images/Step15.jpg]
Step 15 - Completed soldering


NOTE: These connections are VERY fragile.  We'll address that in a second... but this is probably a great point to test out at least the power connections. You can take the red and black pins, and plug them into your arduino's 3.3v and ground connections respectively. Then power up the arduino.  Your power indicator SHOULD light up, and you can scream out "IT'S ALIVE" and freak out anyone that's around you.

**Step 16: **

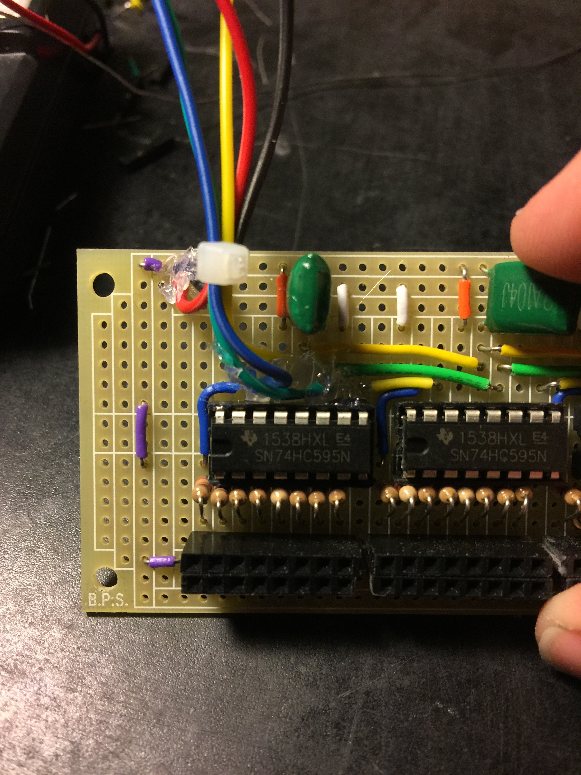
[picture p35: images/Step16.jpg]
Step 16 - Completed soldering


Remove all power to the board, if you happened to test it in the previous step.  Those wires are fragile, so let's hot glue all of the connections we just made in Step 15 to keep them from ripping out. I like to zip tie the wires together, so I know they're all going to end up coming out of the same spot on the board, and then just glob down some glue where they connect to the board. Be careful not to get any hot glue into the socket, or you're going to have a bad day.

**Step 17:**

Again, making sure you don't have any power to the board, and also making sure that your hot glue has cooled... plug in the 74hc595's!  
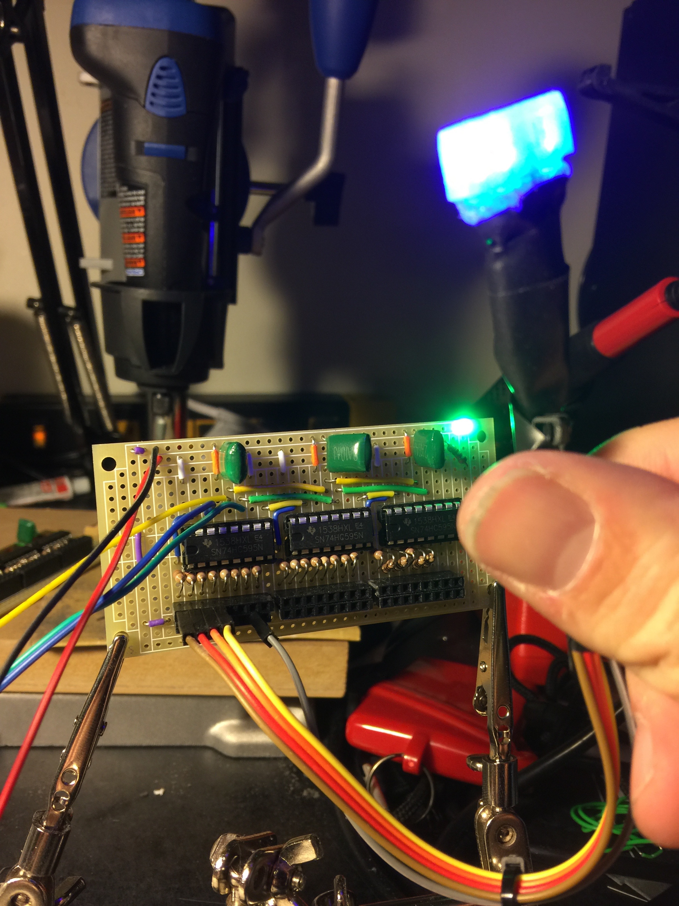
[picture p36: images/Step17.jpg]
Step 17 - Completed soldering


Your board is now complete.  You can safely power it back up.

## To test:
Install the domelights arduino sketch onto your arduino.  Connect the data wire to digital pin 4. Clock to 5. Latch to 8. Power to 3.3v and Ground to ... ground.

Take a 3.3v LED, and put the anode into the top row of the header... the cathode into the bottom row.  (Anode is the long pin... cathode is the short one).

Your LED should immediately start either dimming or flicking on and off (it depends on which part of the animation cycle it's in when you make the connection).

## Troubleshooting:

* - Power indicator isn't lighting up:  

This could happen for a couple of reasons.  The first is that there's no power coming in from the arduino.  test that the arduino has power, and that the connections are good.  You'll need to test your solder points to ensure they're solid and current is flowing. 

If you're SURE the arduino has power... and that your board is getting power... and that the wires are connected to the correct rails of the board.  Then it's possible your LED is in backwards.  this is tricky to troubleshoot if you've already cut the legs off of it... you can run jumper wires from a digital out set to high and the ground, to the pins of the LED, and see if it turns on if you swap them.  It's also possible that the LED is just burnt out.  It's best to test every LED before putting it in the board, but it can happen.

* - Lights come on, but there's no animation:
This has happened to me a few times.  First, reset the arduino with everything plugged in.  If the lights stay on, and don't change... there's a problem with the data, clock, or latch.  Make sure those wires are connected correctly on both the arduino side, and the board side.  Most of the time, it's just that one of them is plugged in to the wrong pin on the arduino side.

Failing that, double check that you've soldered them to the correct location.  The data wire should be soldered to pin 3 of the first socket.  The latch should be soldered to pin 5, and the clock to pin 6.

If all of those are correct, make sure that the connections between socket 1, 2 and 3 are all correct.

If all of the above is correct, you likely have a short in your soldering job somewhere.  You're going to need to take a very good look at the solder points between pins to make sure that there are no points where one terminal strip is connected to another.

* - Lights come on, and there IS animation, but it's weird:

First, let's describe what "weird" is.  When you first power on the board (assuming you have it connected to the arduino, and have successfully uploaded the code)... The logic lights should pulse two to three times (fade from dark to light and back).  The radar eye should be solid red... and the holo and psi should be on solid.  After about 2-3 seconds, the logic lens lights should randomly shift to different animations.  These could either be random lights lighting up, or fading, or some combination of those.  The radar eye should still be solid.  The PSI will either be blue or white... and the holo will be slowly fading through random colors.

See something different?  Are the lights all flickering in unison?  Is the holo solid red(or green or blue), and not changing? Is the PSI red or green? IS THE RED RADAR LED FLICKING OR FADING (that's a big one).  If any of the previous are true, this can be considered "weird". 99.99999999% of the time, this is due to a short in the soldering.  If you've followed the instructions precisely, and all of the wires are connected to the right parts of the shift registers, then it's almost definite that you have a short between solder points.  The only way to fix this (sadly), is to take out a magnifying glass and go from point to point ensuring that things that SHOULD be connected ARE connected, and things that SHOULDN'T be connected AREN'T. It's also helpful to review the points to ensure you have a good solder joint.

For more on common issues with soldering, check out this helpful guide:
https://learn.adafruit.com/adafruit-guide-excellent-soldering/common-problems

Again... this is relatively small work, and it requires a steady hand and clean soldering work.

* - LEDs don't come on:

Any issue with the LED not coming on is going to be a problem with soldering or grounding.  Step through each path that current is supposed to flow, and verify that there is a solid solder connection.  Also, make sure that everything is grounded correctly, and that all of the common ground rails are connected.

* - Other:

Throw me an email at strong.s@gmail.com and we can try to work through it.  The schematic and parts I have are exactly what I've used to make this work, so it should be easy to sort something out quickly over a skype call.

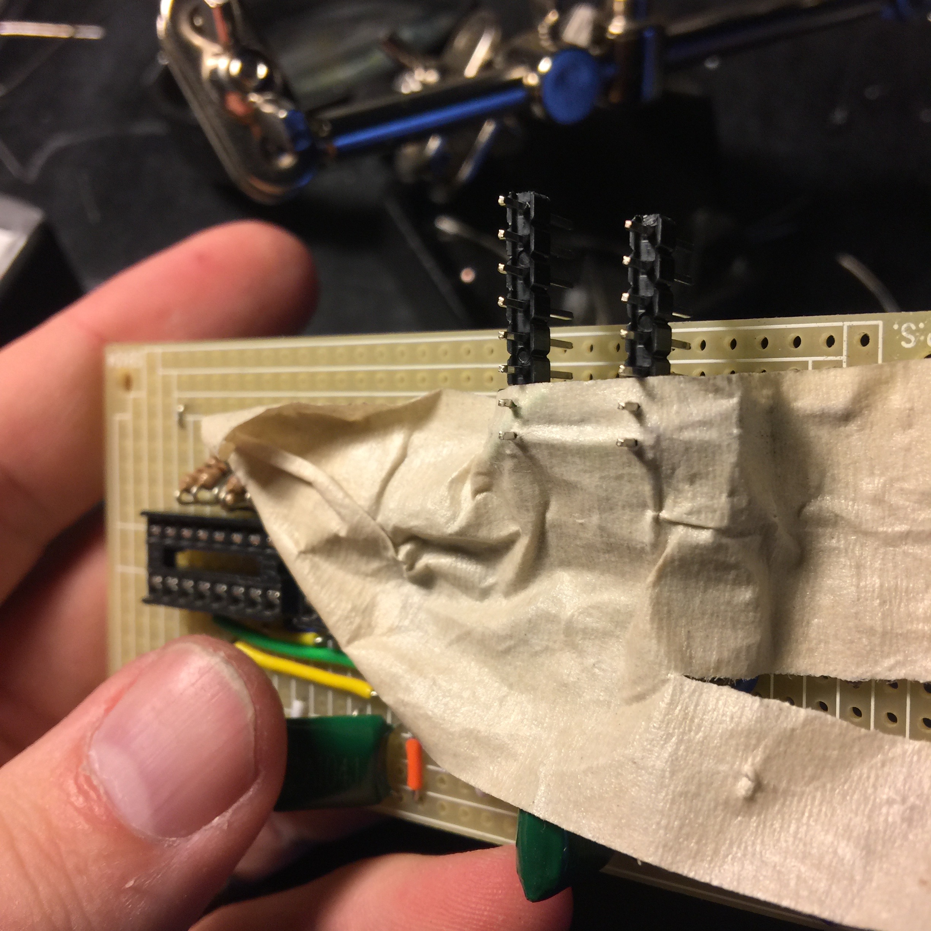
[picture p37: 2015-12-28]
images/Step14B.jpg

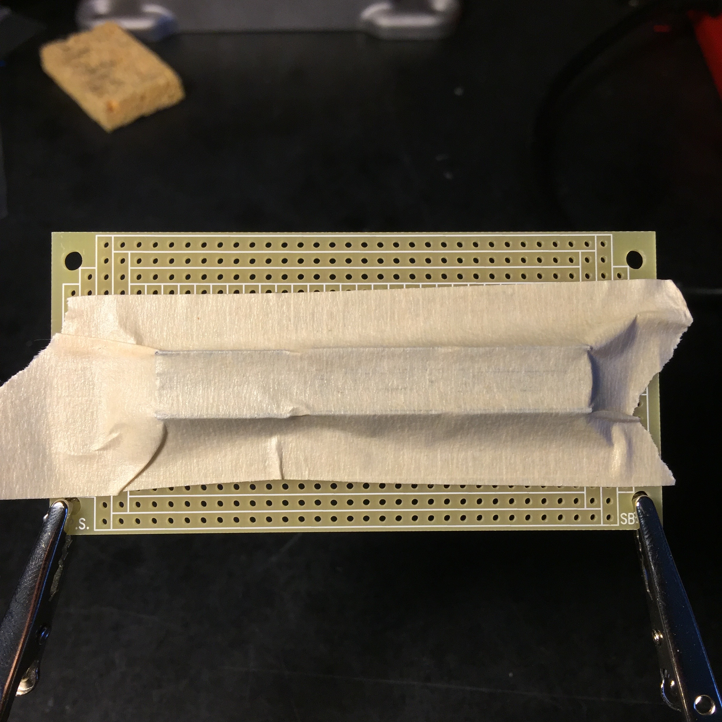
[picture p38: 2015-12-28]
images/Step1B.jpg

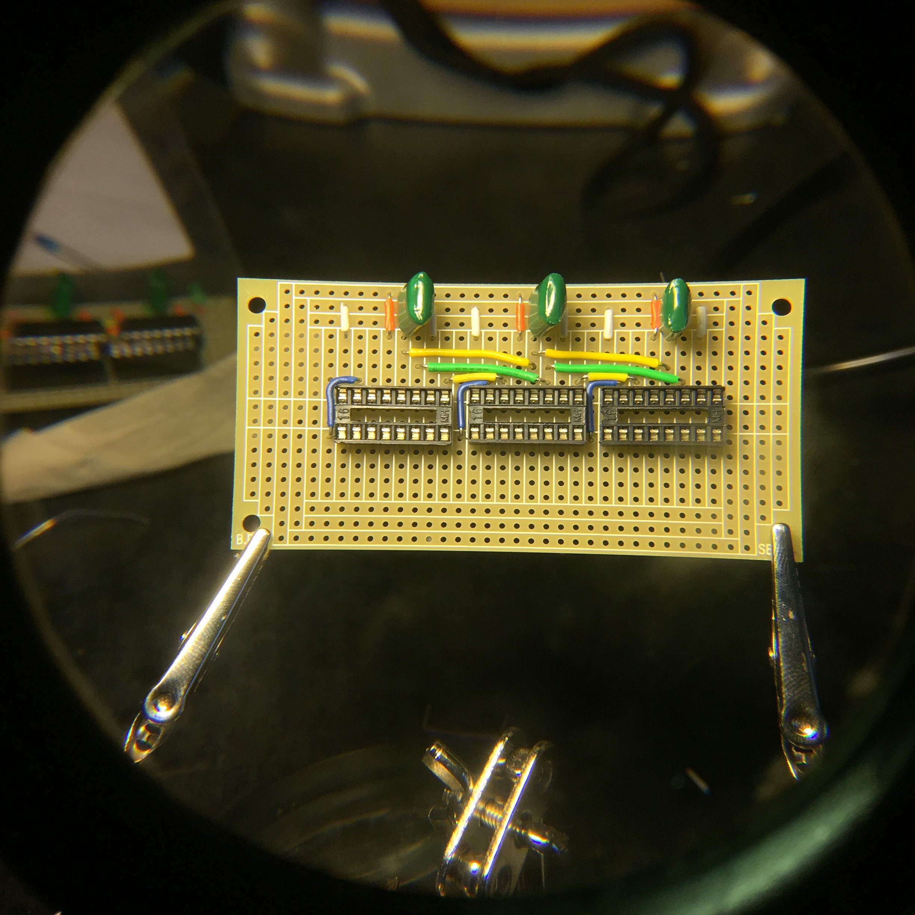
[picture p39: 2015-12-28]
images/Step8B.jpg

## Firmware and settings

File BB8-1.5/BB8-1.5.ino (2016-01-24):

/*************************************************** 
  This is a sketch that controls the lights (and in the near future, audio) for the BB-8 Droid.
  Author : Steven Strong
  Last Modified : Today.
  THIS IS THE LATEST VERSION WITH SOME LEVEL OF SOUND SUPPORT
  SOUND MODULE USED: Adafruit Music Maker

  PROBLEMS: The LED animation freezes during sound playback.
    I'm pretty sure this is as a result of the interrupts being used
    by both the shiftpwm library and the mp3 shield.  I have no idea how to get around this yet.

    
 ****************************************************/
 
// include SPI, MP3 and SD libraries
#include <SPI.h>
#include <Adafruit_VS1053.h>
#include <SdFat.h>
SdFat SD;

#include <Thread.h>
#include <ThreadController.h>
#include <LogicBlock.h>

/***********************************************************
*AUDIO SHIELD SETUP 
***********************************************************/
#define SHIELD_RESET  -1      // VS1053 reset pin (unused!)
#define SHIELD_CS     7      // VS1053 chip select pin (output)
#define SHIELD_DCS    6      // VS1053 Data/command select pin (output)
#define CARDCS 4     // Card chip select pin
#define DREQ 3       // VS1053 Data request, ideally an Interrupt pin
Adafruit_VS1053_FilePlayer musicPlayer = Adafruit_VS1053_FilePlayer(SHIELD_RESET, SHIELD_CS, SHIELD_DCS, DREQ, CARDCS);


/***********************************************************
* LED BLOCKS SETUP
***********************************************************/
// INITIALIZE ALL BLOCKS OF LEDS USING THE LOGICBLOCK OBJECT (startpin, numpins, mode, timeout)
LogicBlock logic1(0,4,0,100); // BLUE LOGIC PANEL
LogicBlock logic2(4,5,0,50); // WHITE LOGIC PANEL 1
LogicBlock logic3(11,5,0,5); // WHITE LOGIC PANEL 2
LogicBlock radar(9,1,0,20);

// SET UP THREADS FOR EACH OF THE BLOCKS
ThreadController controller = ThreadController(); // This will hold pointers to all of the threads

Thread psiThread = Thread();
Thread holoThread = Thread();
Thread logic1Thread = Thread(); // TOP WHITE LOGIC
Thread logic2Thread = Thread(); // BOTTOM WHITE LOGIC
Thread logic3Thread = Thread(); // BLUE LOGIC
Thread radarThread = Thread();
Thread randomizerThread = Thread(); // Controls random display in one of the clusters
Thread audioThread = Thread(); // awww helll yeahhhh

// Random vars
int randomizerTimeout = random(3000,5000);

// AUDIO analysis - Reserved for future use.
//int sensorPin = 8;
//int sensorValue = 0;

// RGB VARS - Note, these pin references are to pins in the lighting rig, not the arduino.
  int PSIRedPin = 16;
  int PSIGreenPin = 17;
  int PSIBluePin = 18;


  // THIS IS NORMAL
//  int HoloRedPin = 19;
//  int HoloGreenPin = 20;
//  int HoloBluePin = 21;
// THIS IS FOR MY BOARD ONLY
  int HoloRedPin = 21;
  int HoloGreenPin = 22;
  int HoloBluePin = 23;

  
  int PSIColor = 1; // 0 - Blue; 1 - White
  int HoloRedTarget = 255;
  int HoloGreenTarget = 255;
  int HoloBlueTarget = 255;
  int HoloRed = 200;
  int HoloGreen = 200;
  int HoloBlue = 200;


// SHIFTPWM SETTINGS
  const int ShiftPWM_latchPin = 22; // YELLOW
// ATTEMPING TO FREE UP SPI FOR SD CARD READER
  #define SHIFTPWM_NOSPI
  const int ShiftPWM_dataPin = 24; // BLUE
  const int ShiftPWM_clockPin = 26; // GREEN 
  const bool ShiftPWM_invertOutputs = false; 
  const bool ShiftPWM_balanceLoad = false;
#include <ShiftPWM.h>   // include ShiftPWM.h after setting the pins!

// SHIFTPWM VARS
  unsigned char maxBrightness = 200;
  unsigned char pwmFrequency = 93;
  int numRegisters = 3;
  int numRGBleds = numRegisters*8/3;

void setup(){
  Serial.begin(9600);

// AUDIO CONFIG
  if (! musicPlayer.begin()) { // initialise the music player
     Serial.println(F("Couldn't find VS1053, do you have the right pins defined?"));
     while (1);
  }
  Serial.println(F("VS1053 found"));
  musicPlayer.sineTest(0x44, 500);    // Make a tone to indicate VS1053 is working
 
  if (!SD.begin(CARDCS)) {
    Serial.println(F("SD failed, or not present"));
    while (1);  // don't do anything more
  }
  Serial.println("SD OK!");
  musicPlayer.setVolume(40,40);
  musicPlayer.useInterrupt(VS1053_FILEPLAYER_TIMER0_INT);
// END AUDIO CONFIG

  
// SHIFT REGISTERS
  ShiftPWM.SetAmountOfRegisters(numRegisters);
  ShiftPWM.Start(pwmFrequency,maxBrightness);
 
  // SET UP ALL OF THE THREADS
  psiThread.setInterval(40);
  psiThread.onRun(PSIColorChange);
  
  holoThread.setInterval(5);
  holoThread.onRun(updateHolo);
 
  logic1Thread.setInterval(logic1.getTimeout());
  logic1Thread.onRun(logic1Cycle);

  logic2Thread.setInterval(logic2.getTimeout());
  logic2Thread.onRun(logic2Cycle);
 
  logic3Thread.setInterval(logic3.getTimeout());
  logic3Thread.onRun(logic3Cycle);

  radarThread.setInterval(radar.getTimeout());
  radarThread.onRun(radarCycle);

  randomizerThread.setInterval(5000);
  randomizerThread.onRun(randomizer);

  audioThread.setInterval(8000);
  audioThread.onRun(pickPlayAudio);

// ADD THREADS TO THREAD CONTROLLER
  controller.add(&psiThread);
  controller.add(&logic1Thread); 
  controller.add(&logic2Thread);
  controller.add(&logic3Thread);
  controller.add(&holoThread);
  controller.add(&radarThread);
  controller.add(&randomizerThread);
  controller.add(&audioThread);
}

void loop()
{ 
  
  controller.run();  // Check/run all threaded processes.
  
}

void pickPlayAudio(){
  String str;
  
  //Serial.println("playing audio file");
  int audioFileNumber = random(1,9);
  str = String(audioFileNumber);
  char filenamePrefix[]   = "BB8-";
  char filenameExtension[] = ".mp3";
  char fileNum[2];
  char combined[10] = {0};
  str.toCharArray(fileNum,2);
  
  strcat(combined, filenamePrefix);
  strcat(combined, fileNum );
  strcat(combined, filenameExtension);

  // FOR SOME REASON, THIS IS NOT RUNNING AS A BACKGROUND PROCESS.  INSTEAD, IT'S ACTING AS THOUGH IT SHOULD PLAY FULL FILE.
  
  if (!musicPlayer.playingMusic){
    if (! musicPlayer.startPlayingFile(combined))  {
    
//        Serial.print("Could not open file ");
 //       Serial.println(combined);
      
    } else {
             Serial.print("Opened ");
             while (musicPlayer.playingMusic){
              Serial.println("this is dumb");
             }
    }
    
  }
}

void updateHolo(){
 
  // does current color match target color?
  if (HoloRedTarget == HoloRed && HoloGreenTarget == HoloGreen && HoloBlueTarget == HoloBlue) {
   //Serial.println("New Holo Color");
    // pick a new target color 
      HoloRedTarget = random(30,150);
      HoloGreenTarget = random(30,150);
      HoloBlueTarget = random(30,150);
     
  } else {
    if (HoloRed < HoloRedTarget) { 
        HoloRed++;
    } else if (HoloRed > HoloRedTarget) {
        HoloRed--;
    }
    if (HoloGreen < HoloGreenTarget) { 
        HoloGreen++;
    } else if (HoloGreen > HoloGreenTarget) {
        HoloGreen--;
    }
    if (HoloBlue < HoloBlueTarget) { 
        HoloBlue++;
    } else if (HoloBlue > HoloBlueTarget) {
        HoloBlue--;
    }
  }
  // HoloRed
                ShiftPWM.SetOne(HoloRedPin,HoloRed);
                ShiftPWM.SetOne(HoloGreenPin,HoloGreen);
                ShiftPWM.SetOne(HoloBluePin,HoloBlue);
               
}

void PSIColorChange(){

   if (musicPlayer.playingMusic){

  Serial.println("Changing colors");
  switch(PSIColor) {
      case 1 :  
               // Serial.println("going white");
                ShiftPWM.SetOne(PSIRedPin,255);
                ShiftPWM.SetOne(PSIGreenPin,255);
                ShiftPWM.SetOne(PSIBluePin,255);
                PSIColor = 2;
                break;
      default : //Serial.println("going blue");
                ShiftPWM.SetOne(PSIRedPin,0); //(GREEN OFF) 
                ShiftPWM.SetOne(PSIGreenPin,0); //(RED OFF) 
                ShiftPWM.SetOne(PSIBluePin,255);
                PSIColor = 1;
                break;
  }
   } else {
      // set blue
                ShiftPWM.SetOne(PSIRedPin,0); //(GREEN OFF) 
                ShiftPWM.SetOne(PSIGreenPin,0); //(RED OFF) 
                ShiftPWM.SetOne(PSIBluePin,255);
   }
  // reset random light change timer
  //PSITimeout = random(1000,9000);
  //psiThread.setInterval(PSITimeout);
 
}


// Functions for the threads to call for the cycles 
void logic1Cycle(){
  logic1.cycle();
  for(int p=0; p<4; p++){
    ShiftPWM.SetOne(logic1.startPin + p, logic1.pinValue[p]);  
  }
  logic1Thread.setInterval(logic1.timeoutValue);
}
void logic2Cycle(){
  logic2.cycle();
  for(int p=0; p<5; p++){
    ShiftPWM.SetOne(logic2.startPin+p, logic2.pinValue[p]);  
  }
  logic2Thread.setInterval(logic2.timeoutValue);

}
void logic3Cycle(){
  logic3.cycle();
  for(int p=0; p<5; p++){
    ShiftPWM.SetOne(logic3.startPin+p, logic3.pinValue[p]);  
  }
  logic3Thread.setInterval(logic3.timeoutValue);
}
void radarCycle(){
  radar.cycle();
  for(int p=0; p<1; p++){
    ShiftPWM.SetOne(radar.startPin + p, radar.pinValue[p]);  
  }
}

void resetAllToPulsing() {
  logic1.setMode(0);
  logic2.setMode(0);
  logic3.setMode(0);
  radar.setMode(0);
}

void randomizer(){
  
  logic1.setMode(random(0,3));
    logic2.setMode(random(0,3));
      logic3.setMode(random(0,3));
  randomizerTimeout = random(3000,5000);
}

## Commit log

2015-12-27 STLs&Schematic
    Added STLs for the optional enclosure and a schematic that needs
    updating.
    [Enclosure-Box.stl, Enclosure-lid.stl]
2015-12-27 Reverted to v1.0
    I inadvertently put some 1.5 code in the master. I’ve reverted the
    changes (and cleaned up a little).
    [BB8.ino]
2015-12-27 Create Board Assembly Instructions
    This is a very rough draft of my assembly instructions... it's not ready for people to actually use... just jotting down the general steps. I will add pictures over the next few days, and refine the 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
2015-12-27 Update Board Assembly Instructions
2015-12-27 Rename Board Assembly Instructions to Board Assembly Instructions.md
2015-12-28 Adding Images
    [Enclosure-Lid-2.0.stl, Enclosure-lid.stl]
2015-12-28 Update Board Assembly Instructions.md
2015-12-29 Updated pinouts for RGB LEDs
    The pinouts in the boards I’m preducing don’t match what I had for my
    prototype board… Just updating to get everything cleaned up
2015-12-29 Updating enclosure lid
    [Enclosure-Lid-2.0.stl, Enclosure-lid-external2.stl]
2015-12-30 Changes to pins for Arduino Mega
    Changed the Latch, Data, and Clock pins to 22,24,and 26 respectively. This will be the final home for these pins in on the Arduino Mega as I prepare for the audio-enabled version. If you're using the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
2015-12-31 Enclosure-Box Updates
    Corrected some issues with the enclosure for the lighting module
    [Enclosure-Box.stl, Enclosure-Box5.stl]
2016-01-12 Adding Delivery Document
    [LogicLenses-NoPSI.stl]
2016-01-12 Updated wire color on radar
2016-01-12 Added radar glue pic
2016-01-12 Added Patrick Stefanski's work
    [ModifiedDomePlate.STL, PowerHolder.STL, PowerHolder_withSupportBlock.STL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]
